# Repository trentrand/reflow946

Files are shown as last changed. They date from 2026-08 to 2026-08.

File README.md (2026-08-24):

# Reflow946

> **Fork notice** — This is a modified version of [Reflow946](https://github.com/DurandA/reflow946)
> by Arnaud Durand, licensed under the [Creative Commons Attribution 4.0 International
> license](LICENSE) (CC BY 4.0). See *Modifications* below for what changed.

The Reflow946 is a Bluetooth LE temperature controller for the 946C electronic hot plate. Using this controller, a reflow profile can be programmed from your web browser using the [Web Bluetooth](https://webbluetoothcg.github.io/web-bluetooth/) API. You can use preset profiles (e.g. for lead-free or leaded soldering) or create a custom profile for a perfect cheese fondue. 🫕

UYUE-946C

The controller board is intended to replace the original controller board. It is **only compatible with the 3 buttons variant** pictured above (see this [teardown](https://youtu.be/Gv2sRJ9y_Ok)). Please send a PR if you adapted the design to a new variant.

## Hardware

The controller is based on a ESP32 module with an IPEX antenna. Since the metal case acts as a Faraday cage, the BLE signal can be improved by taping an antenna outside of the case.

### Front

PCB front

### Back

PCB back

## Status

- [x] Temperature control
  - [x] Temperature control using the front panel
  - [x] [BLE GATT service](https://github.com/DurandA/reflow946-firmware/wiki/GATT-Services) for temperature control
- [x] Reflow profile programming
  - [x] [BLE GATT service](https://github.com/DurandA/reflow946-firmware/wiki/GATT-Services) for reflow profiles
  - [x] [Web Bluetooth application](https://duranda.github.io/reflow946/)

## Modifications

Changes by Trent Rand (Randware), relative to upstream rev 1.2:

- Pathfinder revision (rev 2): 3-digit 7-segment display (`DS1`) replaced by a
  1.47" IPS TFT (ST7789V3, 172x320) with two parallel interfaces:
  `J6` FH12-8S-0.5SH FPC connector (v2 mounting path) and `J9` 2.54mm breakout
  header (bench bring-up). Signals ride the former segment-drive GPIOs:
  BL=dp(IO5) CS=f(IO23) DC=d(IO16) RES=g(IO13) SDA=c(IO19) SCL=d2(IO18).
  One display may be attached at a time (shared bus).
- Second MAX31855KASA (`U6`) with screw terminal `J8` (`EXT_TC`) for top-of-PCB
  thermocouple profiling; shares CLK/MISO with the primary sensor, CS on IO4.
- Breakout `J7` (CLK / MISO / CS_EXT / TC_ADC / 3V3 / GND): digital probe amps
  on the shared SPI bus, or analog amplifiers (AD8495) on TC_ADC = SENSOR_VP.
- IO17/IO22 left as spare GPIOs (I2C-capable; add pull-ups with the device).

Upstream hardware errata and revision notes are preserved in [`hardware/README.md`](hardware/README.md).

## Credits

* Arnaud Durand - Original design ([CC BY 4.0](https://creativecommons.org/licenses/by/4.0/))
* Elías Rodríguez Martín - Revision 1.1, conversion to KiCad
* Trent Rand (Randware) - OLED display interface, external probe interface

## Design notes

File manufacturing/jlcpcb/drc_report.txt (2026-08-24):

** Drc report for reflow946.kicad_pcb **
** Created on 2026-08-24T14:50:08 **
** Report includes: Errors, Warnings, Exclusions **

** Found 258 DRC violations **
[starved_thermal]: Thermal relief connection to zone incomplete (layer F.Cu; zone min spoke count 2; actual 1)
    Local override; error
    @(168.5000 mm, 98.0000 mm): Zone [GND] on F.Cu, priority 0
    @(122.5000 mm, 111.5000 mm): PTH pad 2 [GND] of SW3
[track_dangling]: Track has unconnected end
    Local override; warning
    @(165.5400 mm, 82.3300 mm): Track [+3.3V] on B.Cu, length 4.5800 mm
[via_dangling]: Via is not connected or connected on only one layer
    Local override; warning
    @(154.0500 mm, 96.3000 mm): Via [/dp] on F.Cu - B.Cu
[track_dangling]: Track has unconnected end
    Local override; warning
    @(150.2600 mm, 86.9800 mm): Track [/d2] on F.Cu, length 0.0283 mm
[silk_edge_clearance]: Silkscreen clipped by board edge
    Rule: board setup constraints silk; warning
    @(174.5007 mm, 101.0007 mm): Segment on Edge.Cuts
    @(172.6600 mm, 120.3100 mm): Segment of U1 on F.Silkscreen
[silk_edge_clearance]: Silkscreen clipped by board edge
    Rule: board setup constraints silk; warning
    @(174.5007 mm, 101.0007 mm): Segment on Edge.Cuts
    @(174.9100 mm, 112.5700 mm): Arc of U1 on F.Silkscreen
[silk_edge_clearance]: Silkscreen clipped by board edge
    Rule: board setup constraints silk; warning
    @(103.7000 mm, 126.4000 mm): NPTH pad of REF**
    @(106.6300 mm, 127.6800 mm): Reference field of J7
[lib_footprint_mismatch]: Footprint 'PinHeader_2x03_P2.54mm_Vertical' does not match copy in library 'Connector_PinHeader_2.54mm'
    Local override; warning
    @(108.6750 mm, 74.0750 mm): Footprint J5
[lib_footprint_mismatch]: Footprint 'ESP32-WROOM-32U' does not match copy in library 'RF_Module'
    Local override; warning
    @(116.0000 mm, 99.8000 mm): Footprint U2
[lib_footprint_mismatch]: Footprint 'R_0603_1608Metric_Pad0.98x0.95mm_HandSolder' does not match copy in library 'Resistor_SMD'
    Local override; warning
    @(143.9000 mm, 92.2000 mm): Footprint R12
[lib_footprint_mismatch]: Footprint 'C_0805_2012Metric_Pad1.18x1.45mm_HandSolder' does not match copy in library 'Capacitor_SMD'
    Local override; warning
    @(112.9000 mm, 111.7000 mm): Footprint C6
[lib_footprint_mismatch]: Footprint 'C_0805_2012Metric_Pad1.18x1.45mm_HandSolder' does not match copy in library 'Capacitor_SMD'
    Local override; warning
    @(133.4000 mm, 72.9000 mm): Footprint C3
[lib_footprint_mismatch]: Footprint 'R_0603_1608Metric_Pad0.98x0.95mm_HandSolder' does not match copy in library 'Resistor_SMD'
    Local override; warning
    @(154.5000 mm, 120.0000 mm): Footprint R9
[lib_footprint_mismatch]: Footprint 'C_0805_2012Metric_Pad1.18x1.45mm_HandSolder' does not match copy in library 'Capacitor_SMD'
    Local override; warning
    @(107.7000 mm, 111.7000 mm): Footprint C5
[lib_footprint_mismatch]: Footprint 'R_0603_1608Metric_Pad0.98x0.95mm_HandSolder' does not match copy in library 'Resistor_SMD'
    Local override; warning
    @(108.0770 mm, 116.2000 mm): Footprint FB1
[lib_footprint_mismatch]: Footprint 'R_0603_1608Metric_Pad0.98x0.95mm_HandSolder' does not match copy in library 'Resistor_SMD'
    Local override; warning
    @(108.0770 mm, 118.6000 mm): Footprint FB2
[lib_footprint_mismatch]: Footprint 'R_0603_1608Metric_Pad0.98x0.95mm_HandSolder' does not match copy in library 'Resistor_SMD'
    Local override; warning
    @(117.7000 mm, 111.9000 mm): Footprint R1
[lib_footprint_mismatch]: Footprint 'R_0603_1608Metric_Pad0.98x0.95mm_HandSolder' does not match copy in library 'Resistor_SMD'
    Local override; warning
    @(146.4000 mm, 72.9000 mm): Footprint R17
[lib_footprint_mismatch]: Footprint 'R_0603_1608Metric_Pad0.98x0.95mm_HandSolder' does not match copy in library 'Resistor_SMD'
    Local override; warning
    @(143.9000 mm, 72.9000 mm): Footprint R16
[lib_footprint_mismatch]: Footprint 'CP_Radial_D10.0mm_P5.00mm' does not match copy in library 'Capacitor_THT'
    Local override; warning
    @(122.0000 mm, 78.2677 mm): Footprint C1
[lib_footprint_mismatch]: Footprint 'R_0603_1608Metric_Pad0.98x0.95mm_HandSolder' does not match copy in library 'Resistor_SMD'
    Local override; warning
    @(141.4000 mm, 92.2000 mm): Footprint R13
[lib_footprint_mismatch]: Footprint 'JST_VH_B2P3-VH_1x02_P7.92mm_Vertical' does not match copy in library 'Connector_JST'
    Local override; warning
    @(199.9000 mm, 94.6500 mm): Footprint J2
[lib_footprint_mismatch]: Footprint 'SOT-223-3_TabPin2' does not match copy in library 'Package_TO_SOT_SMD'
    Local override; warning
    @(131.2000 mm, 79.3000 mm): Footprint U4
[lib_footprint_mismatch]: Footprint 'JST_VH_B2P3-VH_1x02_P7.92mm_Vertical' does not match copy in library 'Connector_JST'
    Local override; warning
    @(199.9000 mm, 81.6500 mm): Footprint J3
[lib_footprint_mismatch]: Footprint 'R_Axial_DIN0414_L11.9mm_D4.5mm_P15.24mm_Horizontal' does not match copy in library 'Resistor_THT'
    Local override; warning
    @(190.9062 mm, 118.4605 mm): Footprint R5
[lib_footprint_mismatch]: Footprint 'C_0805_2012Metric_Pad1.18x1.45mm_HandSolder' does not match copy in library 'Capacitor_SMD'
    Local override; warning
    @(129.1000 mm, 72.9000 mm): Footprint C2
[lib_footprint_mismatch]: Footprint 'C_0805_2012Metric_Pad1.18x1.45mm_HandSolder' does not match copy in library 'Capacitor_SMD'
    Local override; warning
    @(110.8710 mm, 117.4000 mm): Footprint C4
[lib_footprint_mismatch]: Footprint 'SOT-23' does not match copy in library 'Package_TO_SOT_SMD'
    Local override; warning
    @(143.2000 mm, 80.9683 mm): Footprint Q3
[lib_footprint_mismatch]: Footprint 'R_0603_1608Metric_Pad0.98x0.95mm_HandSolder' does not match copy in library 'Resistor_SMD'
    Local override; warning
    @(148.2000 mm, 85.6839 mm): Footprint R18
[lib_footprint_mismatch]: Footprint 'DIP-6_W7.62mm_LongPads' does not match copy in library 'Package_DIP'
    Local override; warning
    @(171.1000 mm, 113.9000 mm): Footprint U1
[lib_footprint_mismatch]: Footprint 'R_Axial_DIN0309_L9.0mm_D3.2mm_P12.70mm_Horizontal' does not match copy in library 'Resistor_THT'
    Local override; warning
    @(178.1500 mm, 99.7000 mm): Footprint R4
[lib_footprint_mismatch]: Footprint 'R_0603_1608Metric_Pad0.98x0.95mm_HandSolder' does not match copy in library 'Resistor_SMD'
    Local override; warning
    @(143.2000 mm, 85.6839 mm): Footprint R19
[lib_footprint_mismatch]: Footprint 'R_0603_1608Metric_Pad0.98x0.95mm_HandSolder' does not match copy in library 'Resistor_SMD'
    Local override; warning
    @(138.9000 mm, 72.9000 mm): Footprint R15
[lib_footprint_mismatch]: Footprint 'SOT-23' does not match copy in library 'Package_TO_SOT_SMD'
    Local override; warning
    @(138.1000 mm, 80.9683 mm): Footprint Q4
[lib_footprint_mismatch]: Footprint 'R_0603_1608Metric_Pad0.98x0.95mm_HandSolder' does not match copy in library 'Resistor_SMD'
    Local override; warning
    @(138.8000 mm, 92.2000 mm): Footprint R14
[lib_footprint_mismatch]: Footprint 'JST_VH_B2P-VH_1x02_P3.96mm_Vertical' does not match copy in library 'Connector_JST'
    Local override; warning
    @(104.1000 mm, 84.0000 mm): Footprint J1
[lib_footprint_mismatch]: Footprint 'R_Axial_DIN0309_L9.0mm_D3.2mm_P12.70mm_Horizontal' does not match copy in library 'Resistor_THT'
    Local override; warning
    @(183.5000 mm, 118.9000 mm): Footprint R3
[lib_footprint_mismatch]: Footprint 'SOT-23' does not match copy in library 'Package_TO_SOT_SMD'
    Local override; warning
    @(148.0000 mm, 80.9683 mm): Footprint Q2
[lib_footprint_mismatch]: Footprint 'Fuse_0805_2012Metric_Pad1.15x1.40mm_HandSolder' does not match copy in library 'Fuse'
    Local override; warning
    @(111.7000 mm, 80.0000 mm): Footprint F1
[lib_footprint_mismatch]: Footprint 'R_0603_1608Metric_Pad0.98x0.95mm_HandSolder' does not match copy in library 'Resistor_SMD'
    Local override; warning
    @(127.5000 mm, 120.0000 mm): Footprint R7
[lib_footprint_mismatch]: Footprint 'R_0603_1608Metric_Pad0.98x0.95mm_HandSolder' does not match copy in library 'Resistor_SMD'
    Local override; warning
    @(138.2000 mm, 85.6839 mm): Footprint R20
[lib_footprint_mismatch]: Footprint 'TO-220-3_Horizontal_TabUp' does not match copy in library 'Package_TO_SOT_THT'
    Local override; warning
    @(183.2000 mm, 94.0550 mm): Footprint Q1
[lib_footprint_mismatch]: Footprint 'SOIC-8_3.9x4.9mm_P1.27mm' does not match copy in library 'Package_SO'
    Local override; warning
    @(114.9000 mm, 117.6000 mm): Footprint U3
[lib_footprint_mismatch]: Footprint 'R_0603_1608Metric_Pad0.98x0.95mm_HandSolder' does not match copy in library 'Resistor_SMD'
    Local override; warning
    @(146.5000 mm, 92.2000 mm): Footprint R11
[lib_footprint_mismatch]: Footprint 'R_0603_1608Metric_Pad0.98x0.95mm_HandSolder' does not match copy in library 'Resistor_SMD'
    Local override; warning
    @(138.5000 mm, 120.0000 mm): Footprint R8
[lib_footprint_mismatch]: Footprint 'R_0603_1608Metric_Pad0.98x0.95mm_HandSolder' does not match copy in library 'Resistor_SMD'
    Local override; warning
    @(149.0000 mm, 92.2000 mm): Footprint R10
[lib_footprint_mismatch]: Footprint 'R_0603_1608Metric_Pad0.98x0.95mm_HandSolder' does not match copy in library 'Resistor_SMD'
    Local override; warning
    @(110.3000 mm, 111.9000 mm): Footprint R6
[lib_footprint_mismatch]: Footprint 'C_Rect_L13.0mm_W6.0mm_P10.00mm_FKS3_FKP3_MKS4' does not match copy in library 'Capacitor_THT'
    Local override; warning
    @(197.8000 mm, 118.5000 mm): Footprint CCBB1
[text_height]: Text height out of range (board setup constraints silk text height min height 0.8000 mm; actual 0.7000 mm)
    Rule: board setup constraints silk text height; warning
    @(142.6200 mm, 128.9000 mm): PCB text 'Based on Reflow946 by A. Durand | CC BY 4.0' on F.Silkscreen
[silk_overlap]: Silkscreen clearance
    Rule: board setup constraints silk; warning
    @(145.1113 mm, 103.2000 mm): Reference field of J8
    @(143.7912 mm, 103.0300 mm): Reference field of FB3
[silk_overlap]: Silkscreen clearance
    Rule: board setup constraints silk; warning
    @(143.3775 mm, 92.4547 mm): Segment of R12 on F.Silkscreen
    @(124.6250 mm, 72.7250 mm): Rectangle on F.Silkscreen
[silk_overlap]: Silkscreen clearance
    Rule: board setup constraints silk; warning
    @(140.8775 mm, 92.4547 mm): Segment of R13 on F.Silkscreen
    @(124.6250 mm, 72.7250 mm): Rectangle on F.Silkscreen
[silk_overlap]: Silkscreen clearance
    Rule: board setup constraints silk; warning
    @(143.5365 mm, 102.5825 mm): Segment of FB4 on F.Silkscreen
    @(143.7912 mm, 103.0300 mm): Reference field of FB3
[silk_overlap]: Silkscreen clearance
    Rule: board setup constraints silk; warning
    @(138.2775 mm, 92.4547 mm): Segment of R14 on F.Silkscreen
    @(124.6250 mm, 72.7250 mm): Rectangle on F.Silkscreen
[silk_overlap]: Silkscreen clearance
    Rule: board setup constraints silk; warning
    @(124.6250 mm, 72.7250 mm): Rectangle on F.Silkscreen
    @(139.3225 mm, 92.4547 mm): Segment of R14 on F.Silkscreen
[silk_overlap]: Silkscreen clearance
    Rule: board setup constraints silk; warning
    @(144.4225 mm, 92.4547 mm): Segment of R12 on F.Silkscreen
    @(124.6250 mm, 72.7250 mm): Rectangle on F.Silkscreen
[silk_overlap]: Silkscreen clearance
    Rule: board setup constraints silk; warning
    @(124.6250 mm, 72.7250 mm): Rectangle on F.Silkscreen
    @(141.9225 mm, 92.4547 mm): Segment of R13 on F.Silkscreen
[silk_overlap]: Silkscreen clearance
    Rule: board setup constraints silk; warning
    @(124.6250 mm, 72.7250 mm): Rectangle on F.Silkscreen
    @(145.9775 mm, 92.4547 mm): Segment of R11 on F.Silkscreen
[silk_overlap]: Silkscreen clearance
    Rule: board setup constraints silk; warning
    @(147.0225 mm, 92.4547 mm): Segment of R11 on F.Silkscreen
    @(124.6250 mm, 72.7250 mm): Rectangle on F.Silkscreen
[silk_overlap]: Silkscreen clearance
    Rule: board setup constraints silk; warning
    @(148.4775 mm, 92.4547 mm): Segment of R10 on F.Silkscreen
    @(124.6250 mm, 72.7250 mm): Rectangle on F.Silkscreen
[silk_overlap]: Silkscreen clearance
    Rule: board setup constraints silk; warning
    @(124.6250 mm, 72.7250 mm): Rectangle on F.Silkscreen
    @(149.5225 mm, 92.4547 mm): Segment of R10 on F.Silkscreen
[silk_overlap]: Silkscreen clearance
    Rule: board setup constraints silk; warning
    @(126.4250 mm, 73.7250 mm): Rectangle on F.Silkscreen
    @(154.2900 mm, 91.0400 mm): Segment of J9 on F.Silkscreen
[silk_overlap]: Silkscreen clearance
    Rule: board setup constraints silk; warning
    @(126.4250 mm, 73.7250 mm): Rectangle on F.Silkscreen
    @(155.6700 mm, 91.0400 mm): Segment of J9 on F.Silkscreen
[silk_overlap]: Silkscreen clearance
    Rule: board setup constraints silk; warning
    @(126.4250 mm, 73.7250 mm): Rectangle on F.Silkscreen
    @(147.9000 mm, 72.9000 mm): Reference field of R17
[silk_overlap]: Silkscreen clearance
    Rule: board setup constraints silk; warning
    @(124.6250 mm, 72.7250 mm): Rectangle on F.Silkscreen
    @(147.9000 mm, 72.9000 mm): Reference field of R17
[silk_overlap]: Silkscreen clearance
    Rule: board setup constraints silk; warning
    @(145.8775 mm, 72.6453 mm): Segment of R17 on F.Silkscreen
    @(124.6250 mm, 72.7250 mm): Rectangle on F.Silkscreen
[silk_overlap]: Silkscreen clearance
    Rule: board setup constraints silk; warning
    @(124.6250 mm, 72.7250 mm): Rectangle on F.Silkscreen
    @(146.9225 mm, 72.6453 mm): Segment of R17 on F.Silkscreen
[silk_overlap]: Silkscreen clearance
    Rule: board setup constraints silk; warning
    @(126.4250 mm, 73.7250 mm): Rectangle on F.Silkscreen
    @(142.5000 mm, 72.9000 mm): Reference field of R16
[silk_overlap]: Silkscreen clearance
    Rule: board setup constraints silk; warning
    @(124.6250 mm, 72.7250 mm): Rectangle on F.Silkscreen
    @(142.5000 mm, 72.9000 mm): Reference field of R16
[silk_overlap]: Silkscreen clearance
    Rule: board setup constraints silk; warning
    @(124.6250 mm, 72.7250 mm): Rectangle on F.Silkscreen
    @(143.3775 mm, 72.6453 mm): Segment of R16 on F.Silkscreen
[silk_overlap]: Silkscreen clearance
    Rule: board setup constraints silk; warning
    @(124.6250 mm, 72.7250 mm): Rectangle on F.Silkscreen
    @(144.4225 mm, 72.6453 mm): Segment of R16 on F.Silkscreen
[silk_overlap]: Silkscreen clearance
    Rule: board setup constraints silk; warning
    @(142.6250 mm, 71.1750 mm): PCB text 'ST7789V3 ALIGN 32.4x17.3' on F.Silkscreen
    @(133.4000 mm, 71.3000 mm): Reference field of C3
[silk_overlap]: Silkscreen clearance
    Rule: board setup constraints silk; warning
    @(126.4250 mm, 73.7250 mm): Rectangle on F.Silkscreen
    @(140.3300 mm, 72.9000 mm): Reference field of R15
[silk_overlap]: Silkscreen clearance
    Rule: board setup constraints silk; warning
    @(140.3300 mm, 72.9000 mm): Reference field of R15
    @(124.6250 mm, 72.7250 mm): Rectangle on F.Silkscreen
[silk_overlap]: Silkscreen clearance
    Rule: board setup constraints silk; warning
    @(124.6250 mm, 72.7250 mm): Rectangle on F.Silkscreen
    @(138.3775 mm, 72.6453 mm): Segment of R15 on F.Silkscreen
[silk_overlap]: Silkscreen clearance
    Rule: board setup constraints silk; warning
    @(139.4225 mm, 72.6453 mm): Segment of R15 on F.Silkscreen
    @(124.6250 mm, 72.7250 mm): Rectangle on F.Silkscreen
[silk_overlap]: Silkscreen clearance
    Rule: board setup constraints silk; warning
    @(126.4250 mm, 73.7250 mm): Rectangle on F.Silkscreen
    @(133.1387 mm, 73.6350 mm): Segment of C3 on F.Silkscreen
[silk_overlap]: Silkscreen clearance
    Rule: board setup constraints silk; warning
    @(129.3613 mm, 73.6350 mm): Segment of C2 on F.Silkscreen
    @(126.4250 mm, 73.7250 mm): Rectangle on F.Silkscreen
[silk_overlap]: Silkscreen clearance
    Rule: board setup constraints silk; warning
    @(116.9300 mm, 75.4477 mm): Segment of C1 on F.Silkscreen
    @(124.6250 mm, 72.7250 mm): Rectangle on F.Silkscreen
[silk_overlap]: Silkscreen clearance
    Rule: board setup constraints silk; warning
    @(126.4250 mm, 73.7250 mm): Rectangle on F.Silkscreen
    @(116.9300 mm, 75.4477 mm): Segment of C1 on F.Silkscreen
[silk_overlap]: Silkscreen clearance
    Rule: board setup constraints silk; warning
    @(124.6250 mm, 72.7250 mm): Rectangle on F.Silkscreen
    @(116.9320 mm, 75.4077 mm): Segment of C1 on F.Silkscreen
[silk_overlap]: Silkscreen clearance
    Rule: board setup constraints silk; warning
    @(126.4250 mm, 73.7250 mm): Rectangle on F.Silkscreen
    @(116.9320 mm, 75.4077 mm): Segment of C1 on F.Silkscreen
[silk_overlap]: Silkscreen clearance
    Rule: board setup constraints silk; warning
    @(116.9350 mm, 75.3677 mm): Segment of C1 on F.Silkscreen
    @(124.6250 mm, 72.7250 mm): Rectangle on F.Silkscreen
[silk_overlap]: Silkscreen clearance
    Rule: board setup constraints silk; warning
    @(126.4250 mm, 73.7250 mm): Rectangle on F.Silkscreen
    @(116.9350 mm, 75.3677 mm): Segment of C1 on F.Silkscreen
[silk_overlap]: Silkscreen clearance
    Rule: board setup constraints silk; warning
    @(124.6250 mm, 72.7250 mm): Rectangle on F.Silkscreen
    @(116.9380 mm, 75.3277 mm): Segment of C1 on F.Silkscreen
[silk_overlap]: Silkscreen clearance
    Rule: board setup constraints silk; warning
    @(126.4250 mm, 73.7250 mm): Rectangle on F.Silkscreen
    @(116.9380 mm, 75.3277 mm): Segment of C1 on F.Silkscreen
[silk_overlap]: Silkscreen clearance
    Rule: board setup constraints silk; warning
    @(124.6250 mm, 72.7250 mm): Rectangle on F.Silkscreen
    @(116.9420 mm, 75.2877 mm): Segment of C1 on F.Silkscreen
[silk_overlap]: Silkscreen clearance
    Rule: board setup constraints silk; warning
    @(126.4250 mm, 73.7250 mm): Rectangle on F.Silkscreen
    @(116.9420 mm, 75.2877 mm): Segment of C1 on F.Silkscreen
[silk_overlap]: Silkscreen clearance
    Rule: board setup constraints silk; warning
    @(124.6250 mm, 72.7250 mm): Rectangle on F.Silkscreen
    @(116.9460 mm, 75.2477 mm): Segment of C1 on F.Silkscreen
[silk_overlap]: Silkscreen clearance
    Rule: board setup constraints silk; warning
    @(126.4250 mm, 73.7250 mm): Rectangle on F.Silkscreen
    @(116.9460 mm, 75.2477 mm): Segment of C1 on F.Silkscreen
[silk_overlap]: Silkscreen clearance
    Rule: board setup constraints silk; warning
    @(124.6250 mm, 72.7250 mm): Rectangle on F.Silkscreen
    @(116.9500 mm, 75.2077 mm): Segment of C1 on F.Silkscreen
[silk_overlap]: Silkscreen clearance
    Rule: board setup constraints silk; warning
    @(126.4250 mm, 73.7250 mm): Rectangle on F.Silkscreen
    @(116.9500 mm, 75.2077 mm): Segment of C1 on F.Silkscreen
[silk_overlap]: Silkscreen clearance
    Rule: board setup constraints silk; warning
    @(124.6250 mm, 72.7250 mm): Rectangle on F.Silkscreen
    @(116.9550 mm, 75.1677 mm): Segment of C1 on F.Silkscreen
[silk_overlap]: Silkscreen clearance
    Rule: board setup constraints silk; warning
    @(126.4250 mm, 73.7250 mm): Rectangle on F.Silkscreen
    @(116.9550 mm, 75.1677 mm): Segment of C1 on F.Silkscreen
[silk_overlap]: Silkscreen clearance
    Rule: board setup constraints silk; warning
    @(124.6250 mm, 72.7250 mm): Rectangle on F.Silkscreen
    @(116.9600 mm, 75.1277 mm): Segment of C1 on F.Silkscreen
[silk_overlap]: Silkscreen clearance
    Rule: board setup constraints silk; warning
    @(126.4250 mm, 73.7250 mm): Rectangle on F.Silkscreen
    @(116.9600 mm, 75.1277 mm): Segment of C1 on F.Silkscreen
[silk_overlap]: Silkscreen clearance
    Rule: board setup constraints silk; warning
    @(124.6250 mm, 72.7250 mm): Rectangle on F.Silkscreen
    @(116.9650 mm, 75.0877 mm): Segment of C1 on F.Silkscreen
[silk_overlap]: Silkscreen clearance
    Rule: board setup constraints silk; warning
    @(126.4250 mm, 73.7250 mm): Rectangle on F.Silkscreen
    @(116.9650 mm, 75.0877 mm): Segment of C1 on F.Silkscreen
[silk_overlap]: Silkscreen clearance
    Rule: board setup constraints silk; warning
    @(124.6250 mm, 72.7250 mm): Rectangle on F.Silkscreen
    @(116.9700 mm, 75.0467 mm): Segment of C1 on F.Silkscreen
[silk_overlap]: Silkscreen clearance
    Rule: board setup constraints silk; warning
    @(126.4250 mm, 73.7250 mm): Rectangle on F.Silkscreen
    @(116.9700 mm, 75.0467 mm): Segment of C1 on F.Silkscreen
[silk_overlap]: Silkscreen clearance
    Rule: board setup constraints silk; warning
    @(124.6250 mm, 72.7250 mm): Rectangle on F.Silkscreen
    @(116.9760 mm, 75.0067 mm): Segment of C1 on F.Silkscreen
[silk_overlap]: Silkscreen clearance
    Rule: board setup constraints silk; warning
    @(126.4250 mm, 73.7250 mm): Rectangle on F.Silkscreen
    @(116.9760 mm, 75.0067 mm): Segment of C1 on F.Silkscreen
[silk_overlap]: Silkscreen clearance
    Rule: board setup constraints silk; warning
    @(124.6250 mm, 72.7250 mm): Rectangle on F.Silkscreen
    @(116.9820 mm, 74.9667 mm): Segment of C1 on F.Silkscreen
[silk_overlap]: Silkscreen clearance
    Rule: board setup constraints silk; warning
    @(126.4250 mm, 73.7250 mm): Rectangle on F.Silkscreen
    @(116.9820 mm, 74.9667 mm): Segment of C1 on F.Silkscreen
[silk_overlap]: Silkscreen clearance
    Rule: board setup constraints silk; warning
    @(116.9890 mm, 74.9267 mm): Segment of C1 on F.Silkscreen
    @(124.6250 mm, 72.7250 mm): Rectangle on F.Silkscreen
[silk_overlap]: Silkscreen clearance
    Rule: board setup constraints silk; warning
    @(126.4250 mm, 73.7250 mm): Rectangle on F.Silkscreen
    @(116.9890 mm, 74.9267 mm): Segment of C1 on F.Silkscreen
[silk_overlap]: Silkscreen clearance
    Rule: board setup constraints silk; warning
    @(116.9960 mm, 74.8867 mm): Segment of C1 on F.Silkscreen
    @(124.6250 mm, 72.7250 mm): Rectangle on F.Silkscreen
[silk_overlap]: Silkscreen clearance
    Rule: board setup constraints silk; warning
    @(126.4250 mm, 73.7250 mm): Rectangle on F.Silkscreen
    @(116.9960 mm, 74.8867 mm): Segment of C1 on F.Silkscreen
[silk_overlap]: Silkscreen clearance
    Rule: board setup constraints silk; warning
    @(124.6250 mm, 72.7250 mm): Rectangle on F.Silkscreen
    @(117.0030 mm, 74.8467 mm): Segment of C1 on F.Silkscreen
[silk_overlap]: Silkscreen clearance
    Rule: board setup constraints silk; warning
    @(126.4250 mm, 73.7250 mm): Rectangle on F.Silkscreen
    @(117.0030 mm, 74.8467 mm): Segment of C1 on F.Silkscreen
[silk_overlap]: Silkscreen clearance
    Rule: board setup constraints silk; warning
    @(124.6250 mm, 72.7250 mm): Rectangle on F.Silkscreen
    @(117.0100 mm, 74.8067 mm): Segment of C1 on F.Silkscreen
[silk_overlap]: Silkscreen clearance
    Rule: board setup constraints silk; warning
    @(126.4250 mm, 73.7250 mm): Rectangle on F.Silkscreen
    @(117.0100 mm, 74.8067 mm): Segment of C1 on F.Silkscreen
[silk_overlap]: Silkscreen clearance
    Rule: board setup constraints silk; warning
    @(117.0180 mm, 74.7667 mm): Segment of C1 on F.Silkscreen
    @(124.6250 mm, 72.7250 mm): Rectangle on F.Silkscreen
[silk_overlap]: Silkscreen clearance
    Rule: board setup constraints silk; warning
    @(126.4250 mm, 73.7250 mm): Rectangle on F.Silkscreen
    @(117.0180 mm, 74.7667 mm): Segment of C1 on F.Silkscreen
[silk_overlap]: Silkscreen clearance
    Rule: board setup constraints silk; warning
    @(124.6250 mm, 72.7250 mm): Rectangle on F.Silkscreen
    @(117.0260 mm, 74.7267 mm): Segment of C1 on F.Silkscreen
[silk_overlap]: Silkscreen clearance
    Rule: board setup constraints silk; warning
    @(126.4250 mm, 73.7250 mm): Rectangle on F.Silkscreen
    @(117.0260 mm, 74.7267 mm): Segment of C1 on F.Silkscreen
[silk_overlap]: Silkscreen clearance
    Rule: board setup constraints silk; warning
    @(124.6250 mm, 72.7250 mm): Rectangle on F.Silkscreen
    @(117.0350 mm, 74.6867 mm): Segment of C1 on F.Silkscreen
[silk_overlap]: Silkscreen clearance
    Rule: board setup constraints silk; warning
    @(126.4250 mm, 73.7250 mm): Rectangle on F.Silkscreen
    @(117.0350 mm, 74.6867 mm): Segment of C1 on F.Silkscreen
[silk_overlap]: Silkscreen clearance
    Rule: board setup constraints silk; warning
    @(124.6250 mm, 72.7250 mm): Rectangle on F.Silkscreen
    @(117.0440 mm, 74.6467 mm): Segment of C1 on F.Silkscreen
[silk_overlap]: Silkscreen clearance
    Rule: board setup constraints silk; warning
    @(126.4250 mm, 73.7250 mm): Rectangle on F.Silkscreen
    @(117.0440 mm, 74.6467 mm): Segment of C1 on F.Silkscreen
[silk_overlap]: Silkscreen clearance
    Rule: board setup constraints silk; warning
    @(117.0530 mm, 74.6067 mm): Segment of C1 on F.Silkscreen
    @(124.6250 mm, 72.7250 mm): Rectangle on F.Silkscreen
[silk_overlap]: Silkscreen clearance
    Rule: board setup constraints silk; warning
    @(126.4250 mm, 73.7250 mm): Rectangle on F.Silkscreen
    @(117.0530 mm, 74.6067 mm): Segment of C1 on F.Silkscreen
[silk_overlap]: Silkscreen clearance
    Rule: board setup constraints silk; warning
    @(117.0620 mm, 74.5667 mm): Segment of C1 on F.Silkscreen
    @(124.6250 mm, 72.7250 mm): Rectangle on F.Silkscreen
[silk_overlap]: Silkscreen clearance
    Rule: board setup constraints silk; warning
    @(126.4250 mm, 73.7250 mm): Rectangle on F.Silkscreen
    @(117.0620 mm, 74.5667 mm): Segment of C1 on F.Silkscreen
[silk_overlap]: Silkscreen clearance
    Rule: board setup constraints silk; warning
    @(123.2410 mm, 72.6067 mm): Segment of C1 on F.Silkscreen
    @(124.6250 mm, 72.7250 mm): Rectangle on F.Silkscreen
[silk_overlap]: Silkscreen clearance
    Rule: board setup constraints silk; warning
    @(123.2410 mm, 72.6467 mm): Segment of C1 on F.Silkscreen
    @(124.6250 mm, 72.7250 mm): Rectangle on F.Silkscreen
[silk_overlap]: Silkscreen clearance
    Rule: board setup constraints silk; warning
    @(124.6250 mm, 72.7250 mm): Rectangle on F.Silkscreen
    @(123.2410 mm, 72.6867 mm): Segment of C1 on F.Silkscreen
[silk_overlap]: Silkscreen clearance
    Rule: board setup constraints silk; warning
    @(124.6250 mm, 72.7250 mm): Rectangle on F.Silkscreen
    @(123.2410 mm, 72.7267 mm): Segment of C1 on F.Silkscreen
[silk_overlap]: Silkscreen clearance
    Rule: board setup constraints silk; warning
    @(123.2410 mm, 72.7667 mm): Segment of C1 on F.Silkscreen
    @(124.6250 mm, 72.7250 mm): Rectangle on F.Silkscreen
[silk_overlap]: Silkscreen clearance
    Rule: board setup constraints silk; warning
    @(124.6250 mm, 72.7250 mm): Rectangle on F.Silkscreen
    @(123.2410 mm, 72.8067 mm): Segment of C1 on F.Silkscreen
[silk_overlap]: Silkscreen clearance
    Rule: board setup constraints silk; warning
    @(123.2410 mm, 72.8467 mm): Segment of C1 on F.Silkscreen
    @(124.6250 mm, 72.7250 mm): Rectangle on F.Silkscreen
[silk_overlap]: Silkscreen clearance
    Rule: board setup constraints silk; warning
    @(123.2410 mm, 72.8867 mm): Segment of C1 on F.Silkscreen
    @(124.6250 mm, 72.7250 mm): Rectangle on F.Silkscreen
[silk_overlap]: Silkscreen clearance
    Rule: board setup constraints silk; warning
    @(124.6250 mm, 72.7250 mm): Rectangle on F.Silkscreen
    @(123.2410 mm, 72.9267 mm): Segment of C1 on F.Silkscreen
[silk_overlap]: Silkscreen clearance
    Rule: board setup constraints silk; warning
    @(124.6250 mm, 72.7250 mm): Rectangle on F.Silkscreen
    @(123.2410 mm, 72.9667 mm): Segment of C1 on F.Silkscreen
[silk_overlap]: Silkscreen clearance
    Rule: board setup constraints silk; warning
    @(124.6250 mm, 72.7250 mm): Rectangle on F.Silkscreen
    @(123.2410 mm, 73.0067 mm): Segment of C1 on F.Silkscreen
[silk_overlap]: Silkscreen clearance
    Rule: board setup constraints silk; warning
    @(123.2410 mm, 73.0467 mm): Segment of C1 on F.Silkscreen
    @(124.6250 mm, 72.7250 mm): Rectangle on F.Silkscreen
[silk_overlap]: Silkscreen clearance
    Rule: board setup constraints silk; warning
    @(123.2410 mm, 73.0867 mm): Segment of C1 on F.Silkscreen
    @(124.6250 mm, 72.7250 mm): Rectangle on F.Silkscreen
[silk_overlap]: Silkscreen clearance
    Rule: board setup constraints silk; warning
    @(123.2410 mm, 73.1267 mm): Segment of C1 on F.Silkscreen
    @(124.6250 mm, 72.7250 mm): Rectangle on F.Silkscreen
[silk_overlap]: Silkscreen clearance
    Rule: board setup constraints silk; warning
    @(123.2410 mm, 73.1667 mm): Segment of C1 on F.Silkscreen
    @(124.6250 mm, 72.7250 mm): Rectangle on F.Silkscreen
[silk_overlap]: Silkscreen clearance
    Rule: board setup constraints silk; warning
    @(124.6250 mm, 72.7250 mm): Rectangle on F.Silkscreen
    @(123.2410 mm, 73.2067 mm): Segment of C1 on F.Silkscreen
[silk_overlap]: Silkscreen clearance
    Rule: board setup constraints silk; warning
    @(124.6250 mm, 72.7250 mm): Rectangle on F.Silkscreen
    @(123.2410 mm, 73.2467 mm): Segment of C1 on F.Silkscreen
[silk_overlap]: Silkscreen clearance
    Rule: board setup constraints silk; warning
    @(124.6250 mm, 72.7250 mm): Rectangle on F.Silkscreen
    @(123.2410 mm, 73.2867 mm): Segment of C1 on F.Silkscreen
[silk_overlap]: Silkscreen clearance
    Rule: board setup constraints silk; warning
    @(124.6250 mm, 72.7250 mm): Rectangle on F.Silkscreen
    @(123.2410 mm, 73.3267 mm): Segment of C1 on F.Silkscreen
[silk_overlap]: Silkscreen clearance
    Rule: board setup constraints silk; warning
    @(123.2410 mm, 73.3667 mm): Segment of C1 on F.Silkscreen
    @(124.6250 mm, 72.7250 mm): Rectangle on F.Silkscreen
[silk_overlap]: Silkscreen clearance
    Rule: board setup constraints silk; warning
    @(123.2410 mm, 73.4067 mm): Segment of C1 on F.Silkscreen
    @(124.6250 mm, 72.7250 mm): Rectangle on F.Silkscreen
[silk_overlap]: Silkscreen clearance
    Rule: board setup constraints silk; warning
    @(123.2410 mm, 73.4467 mm): Segment of C1 on F.Silkscreen
    @(124.6250 mm, 72.7250 mm): Rectangle on F.Silkscreen
[silk_overlap]: Silkscreen clearance
    Rule: board setup constraints silk; warning
    @(123.2410 mm, 73.4867 mm): Segment of C1 on F.Silkscreen
    @(124.6250 mm, 72.7250 mm): Rectangle on F.Silkscreen
[silk_overlap]: Silkscreen clearance
    Rule: board setup constraints silk; warning
    @(124.6250 mm, 72.7250 mm): Rectangle on F.Silkscreen
    @(123.2410 mm, 73.5267 mm): Segment of C1 on F.Silkscreen
[silk_overlap]: Silkscreen clearance
    Rule: board setup constraints silk; warning
    @(124.6250 mm, 72.7250 mm): Rectangle on F.Silkscreen
    @(123.2410 mm, 73.5667 mm): Segment of C1 on F.Silkscreen
[silk_overlap]: Silkscreen clearance
    Rule: board setup constraints silk; warning
    @(156.9400 mm, 88.2800 mm): Segment of J9 on F.Silkscreen
    @(124.6250 mm, 72.7250 mm): Rectangle on F.Silkscreen
[silk_overlap]: Silkscreen clearance
    Rule: board setup constraints silk; warning
    @(124.6250 mm, 72.7250 mm): Rectangle on F.Silkscreen
    @(156.9400 mm, 91.0400 mm): Segment of J9 on F.Silkscreen
[silk_overlap]: Silkscreen clearance
    Rule: board setup constraints silk; warning
    @(126.4250 mm, 73.7250 mm): Rectangle on F.Silkscreen
    @(156.9400 mm, 88.2800 mm): Segment of J9 on F.Silkscreen
[silk_overlap]: Silkscreen clearance
    Rule: board setup constraints silk; warning
    @(126.4250 mm, 73.7250 mm): Rectangle on F.Silkscreen
    @(156.9400 mm, 91.0400 mm): Segment of J9 on F.Silkscreen
[silk_overlap]: Silkscreen clearance
    Rule: board setup constraints silk; warning
    @(125.3250 mm, 89.2000 mm): Reference field of U2
    @(124.6250 mm, 72.7250 mm): Rectangle on F.Silkscreen
[silk_overlap]: Silkscreen clearance
    Rule: board setup constraints silk; warning
    @(126.4250 mm, 73.7250 mm): Rectangle on F.Silkscreen
    @(156.9400 mm, 91.0400 mm): Segment of J9 on F.Silkscreen
[silk_overlap]: Silkscreen clearance
    Rule: board setup constraints silk; warning
    @(116.9200 mm, 75.6877 mm): Segment of C1 on F.Silkscreen
    @(124.6250 mm, 72.7250 mm): Rectangle on F.Silkscreen
[silk_overlap]: Silkscreen clearance
    Rule: board setup constraints silk; warning
    @(124.6250 mm, 72.7250 mm): Rectangle on F.Silkscreen
    @(116.9200 mm, 75.7277 mm): Segment of C1 on F.Silkscreen
[silk_overlap]: Silkscreen clearance
    Rule: board setup constraints silk; warning
    @(124.6250 mm, 72.7250 mm): Rectangle on F.Silkscreen
    @(116.9200 mm, 75.7677 mm): Segment of C1 on F.Silkscreen
[silk_overlap]: Silkscreen clearance
    Rule: board setup constraints silk; warning
    @(124.6250 mm, 72.7250 mm): Rectangle on F.Silkscreen
    @(122.0000 mm, 75.7677 mm): Circle of C1 on F.Silkscreen
[silk_overlap]: Silkscreen clearance
    Rule: board setup constraints silk; warning
    @(116.9210 mm, 75.6477 mm): Segment of C1 on F.Silkscreen
    @(124.6250 mm, 72.7250 mm): Rectangle on F.Silkscreen
[silk_overlap]: Silkscreen clearance
    Rule: board setup constraints silk; warning
    @(116.9220 mm, 75.6077 mm): Segment of C1 on F.Silkscreen
    @(124.6250 mm, 72.7250 mm): Rectangle on F.Silkscreen
[silk_overlap]: Silkscreen clearance
    Rule: board setup constraints silk; warning
    @(116.9230 mm, 75.5677 mm): Segment of C1 on F.Silkscreen
    @(124.6250 mm, 72.7250 mm): Rectangle on F.Silkscreen
[silk_overlap]: Silkscreen clearance
    Rule: board setup constraints silk; warning
    @(116.9250 mm, 75.5277 mm): Segment of C1 on F.Silkscreen
    @(124.6250 mm, 72.7250 mm): Rectangle on F.Silkscreen
[silk_overlap]: Silkscreen clearance
    Rule: board setup constraints silk; warning
    @(116.9270 mm, 75.4877 mm): Segment of C1 on F.Silkscreen
    @(124.6250 mm, 72.7250 mm): Rectangle on F.Silkscreen
[silk_overlap]: Silkscreen clearance
    Rule: board setup constraints silk; warning
    @(124.6250 mm, 72.7250 mm): Rectangle on F.Silkscreen
    @(117.0720 mm, 74.5267 mm): Segment of C1 on F.Silkscreen
[silk_overlap]: Silkscreen clearance
    Rule: board setup constraints silk; warning
    @(124.6250 mm, 72.7250 mm): Rectangle on F.Silkscreen
    @(123.2410 mm, 74.2867 mm): Segment of C1 on F.Silkscreen
[silk_overlap]: Silkscreen clearance
    Rule: board setup constraints silk; warning
    @(124.6250 mm, 72.7250 mm): Rectangle on F.Silkscreen
    @(123.2410 mm, 74.3267 mm): Segment of C1 on F.Silkscreen
[silk_overlap]: Silkscreen clearance
    Rule: board setup constraints silk; warning
    @(124.6250 mm, 72.7250 mm): Rectangle on F.Silkscreen
    @(123.2410 mm, 74.3667 mm): Segment of C1 on F.Silkscreen
[silk_overlap]: Silkscreen clearance
    Rule: board setup constraints silk; warning
    @(123.2410 mm, 74.4067 mm): Segment of C1 on F.Silkscreen
    @(124.6250 mm, 72.7250 mm): Rectangle on F.Silkscreen
[silk_overlap]: Silkscreen clearance
    Rule: board setup constraints silk; warning
    @(123.2410 mm, 74.4467 mm): Segment of C1 on F.Silkscreen
    @(124.6250 mm, 72.7250 mm): Rectangle on F.Silkscreen
[silk_overlap]: Silkscreen clearance
    Rule: board setup constraints silk; warning
    @(123.2410 mm, 74.4867 mm): Segment of C1 on F.Silkscreen
    @(124.6250 mm, 72.7250 mm): Rectangle on F.Silkscreen
[silk_overlap]: Silkscreen clearance
    Rule: board setup constraints silk; warning
    @(123.2410 mm, 73.6067 mm): Segment of C1 on F.Silkscreen
    @(124.6250 mm, 72.7250 mm): Rectangle on F.Silkscreen
[silk_overlap]: Silkscreen clearance
    Rule: board setup constraints silk; warning
    @(123.2410 mm, 73.6467 mm): Segment of C1 on F.Silkscreen
    @(124.6250 mm, 72.7250 mm): Rectangle on F.Silkscreen
[silk_overlap]: Silkscreen clearance
    Rule: board setup constraints silk; warning
    @(124.6250 mm, 72.7250 mm): Rectangle on F.Silkscreen
    @(123.2410 mm, 73.6867 mm): Segment of C1 on F.Silkscreen
[silk_overlap]: Silkscreen clearance
    Rule: board setup constraints silk; warning
    @(123.2410 mm, 73.7267 mm): Segment of C1 on F.Silkscreen
    @(124.6250 mm, 72.7250 mm): Rectangle on F.Silkscreen
[silk_overlap]: Silkscreen clearance
    Rule: board setup constraints silk; warning
    @(124.6250 mm, 72.7250 mm): Rectangle on F.Silkscreen
    @(123.2410 mm, 73.7667 mm): Segment of C1 on F.Silkscreen
[silk_overlap]: Silkscreen clearance
    Rule: board setup constraints silk; warning
    @(124.6250 mm, 72.7250 mm): Rectangle on F.Silkscreen
    @(123.2410 mm, 73.8067 mm): Segment of C1 on F.Silkscreen
[silk_overlap]: Silkscreen clearance
    Rule: board setup constraints silk; warning
    @(123.2410 mm, 73.8467 mm): Segment of C1 on F.Silkscreen
    @(124.6250 mm, 72.7250 mm): Rectangle on F.Silkscreen
[silk_overlap]: Silkscreen clearance
    Rule: board setup constraints silk; warning
    @(124.6250 mm, 72.7250 mm): Rectangle on F.Silkscreen
    @(123.2410 mm, 73.8867 mm): Segment of C1 on F.Silkscreen
[silk_overlap]: Silkscreen clearance
    Rule: board setup constraints silk; warning
    @(123.2410 mm, 73.9267 mm): Segment of C1 on F.Silkscreen
    @(124.6250 mm, 72.7250 mm): Rectangle on F.Silkscreen
[silk_overlap]: Silkscreen clearance
    Rule: board setup constraints silk; warning
    @(124.6250 mm, 72.7250 mm): Rectangle on F.Silkscreen
    @(123.2410 mm, 73.9667 mm): Segment of C1 on F.Silkscreen
[silk_overlap]: Silkscreen clearance
    Rule: board setup constraints silk; warning
    @(123.2410 mm, 74.0067 mm): Segment of C1 on F.Silkscreen
    @(124.6250 mm, 72.7250 mm): Rectangle on F.Silkscreen
[silk_overlap]: Silkscreen clearance
    Rule: board setup constraints silk; warning
    @(124.6250 mm, 72.7250 mm): Rectangle on F.Silkscreen
    @(123.2410 mm, 74.0467 mm): Segment of C1 on F.Silkscreen
[silk_overlap]: Silkscreen clearance
    Rule: board setup constraints silk; warning
    @(124.6250 mm, 72.7250 mm): Rectangle on F.Silkscreen
    @(123.2410 mm, 74.0867 mm): Segment of C1 on F.Silkscreen
[silk_overlap]: Silkscreen clearance
    Rule: board setup constraints silk; warning
    @(123.2410 mm, 74.1267 mm): Segment of C1 on F.Silkscreen
    @(124.6250 mm, 72.7250 mm): Rectangle on F.Silkscreen
[silk_overlap]: Silkscreen clearance
    Rule: board setup constraints silk; warning
    @(123.2410 mm, 74.1667 mm): Segment of C1 on F.Silkscreen
    @(124.6250 mm, 72.7250 mm): Rectangle on F.Silkscreen
[silk_overlap]: Silkscreen clearance
    Rule: board setup constraints silk; warning
    @(124.6250 mm, 72.7250 mm): Rectangle on F.Silkscreen
    @(123.2410 mm, 74.2067 mm): Segment of C1 on F.Silkscreen
[silk_overlap]: Silkscreen clearance
    Rule: board setup constraints silk; warning
    @(124.6250 mm, 72.7250 mm): Rectangle on F.Silkscreen
    @(123.2410 mm, 74.2467 mm): Segment of C1 on F.Silkscreen
[silk_overlap]: Silkscreen clearance
    Rule: board setup constraints silk; warning
    @(126.4250 mm, 73.7250 mm): Rectangle on F.Silkscreen
    @(116.9200 mm, 75.6877 mm): Segment of C1 on F.Silkscreen
[silk_overlap]: Silkscreen clearance
    Rule: board setup constraints silk; warning
    @(126.4250 mm, 73.7250 mm): Rectangle on F.Silkscreen
    @(116.9200 mm, 75.7277 mm): Segment of C1 on F.Silkscreen
[silk_overlap]: Silkscreen clearance
    Rule: board setup constraints silk; warning
    @(126.4250 mm, 73.7250 mm): Rectangle on F.Silkscreen
    @(116.9200 mm, 75.7677 mm): Segment of C1 on F.Silkscreen
[silk_overlap]: Silkscreen clearance
    Rule: board setup constraints silk; warning
    @(126.4250 mm, 73.7250 mm): Rectangle on F.Silkscreen
    @(122.0000 mm, 75.7677 mm): Circle of C1 on F.Silkscreen
[silk_overlap]: Silkscreen clearance
    Rule: board setup constraints silk; warning
    @(126.4250 mm, 73.7250 mm): Rectangle on F.Silkscreen
    @(116.9210 mm, 75.6477 mm): Segment of C1 on F.Silkscreen
[silk_overlap]: Silkscreen clearance
    Rule: board setup constraints silk; warning
    @(126.4250 mm, 73.7250 mm): Rectangle on F.Silkscreen
    @(116.9220 mm, 75.6077 mm): Segment of C1 on F.Silkscreen
[silk_overlap]: Silkscreen clearance
    Rule: board setup constraints silk; warning
    @(116.9230 mm, 75.5677 mm): Segment of C1 on F.Silkscreen
    @(126.4250 mm, 73.7250 mm): Rectangle on F.Silkscreen
[silk_overlap]: Silkscreen clearance
    Rule: board setup constraints silk; warning
    @(126.4250 mm, 73.7250 mm): Rectangle on F.Silkscreen
    @(116.9250 mm, 75.5277 mm): Segment of C1 on F.Silkscreen
[silk_overlap]: Silkscreen clearance
    Rule: board setup constraints silk; warning
    @(126.4250 mm, 73.7250 mm): Rectangle on F.Silkscreen
    @(116.9270 mm, 75.4877 mm): Segment of C1 on F.Silkscreen
[silk_overlap]: Silkscreen clearance
    Rule: board setup constraints silk; warning
    @(126.4250 mm, 73.7250 mm): Rectangle on F.Silkscreen
    @(117.0720 mm, 74.5267 mm): Segment of C1 on F.Silkscreen
[silk_overlap]: Silkscreen clearance
    Rule: board setup constraints silk; warning
    @(126.4250 mm, 73.7250 mm): Rectangle on F.Silkscreen
    @(123.2410 mm, 74.2867 mm): Segment of C1 on F.Silkscreen
[silk_overlap]: Silkscreen clearance
    Rule: board setup constraints silk; warning
    @(126.4250 mm, 73.7250 mm): Rectangle on F.Silkscreen
    @(123.2410 mm, 74.3267 mm): Segment of C1 on F.Silkscreen
[silk_overlap]: Silkscreen clearance
    Rule: board setup constraints silk; warning
    @(126.4250 mm, 73.7250 mm): Rectangle on F.Silkscreen
    @(123.2410 mm, 74.3667 mm): Segment of C1 on F.Silkscreen
[silk_overlap]: Silkscreen clearance
    Rule: board setup constraints silk; warning
    @(126.4250 mm, 73.7250 mm): Rectangle on F.Silkscreen
    @(123.2410 mm, 74.4067 mm): Segment of C1 on F.Silkscreen
[silk_overlap]: Silkscreen clearance
    Rule: board setup constraints silk; warning
    @(123.2410 mm, 74.4467 mm): Segment of C1 on F.Silkscreen
    @(126.4250 mm, 73.7250 mm): Rectangle on F.Silkscreen
[silk_overlap]: Silkscreen clearance
    Rule: board setup constraints silk; warning
    @(123.2410 mm, 74.4867 mm): Segment of C1 on F.Silkscreen
    @(126.4250 mm, 73.7250 mm): Rectangle on F.Silkscreen
[silk_overlap]: Silkscreen clearance
    Rule: board setup constraints silk; warning
    @(126.4250 mm, 73.7250 mm): Rectangle on F.Silkscreen
    @(123.2410 mm, 73.6067 mm): Segment of C1 on F.Silkscreen
[silk_overlap]: Silkscreen clearance
    Rule: board setup constraints silk; warning
    @(126.4250 mm, 73.7250 mm): Rectangle on F.Silkscreen
    @(123.2410 mm, 73.6467 mm): Segment of C1 on F.Silkscreen
[silk_overlap]: Silkscreen clearance
    Rule: board setup constraints silk; warning
    @(126.4250 mm, 73.7250 mm): Rectangle on F.Silkscreen
    @(123.2410 mm, 73.6867 mm): Segment of C1 on F.Silkscreen
[silk_overlap]: Silkscreen clearance
    Rule: board setup constraints silk; warning
    @(126.4250 mm, 73.7250 mm): Rectangle on F.Silkscreen
    @(123.2410 mm, 73.7267 mm): Segment of C1 on F.Silkscreen
[silk_overlap]: Silkscreen clearance
    Rule: board setup constraints silk; warning
    @(126.4250 mm, 73.7250 mm): Rectangle on F.Silkscreen
    @(123.2410 mm, 73.7667 mm): Segment of C1 on F.Silkscreen
[silk_overlap]: Silkscreen clearance
    Rule: board setup constraints silk; warning
    @(126.4250 mm, 73.7250 mm): Rectangle on F.Silkscreen
    @(123.2410 mm, 73.8067 mm): Segment of C1 on F.Silkscreen
[silk_overlap]: Silkscreen clearance
    Rule: board setup constraints silk; warning
    @(126.4250 mm, 73.7250 mm): Rectangle on F.Silkscreen
    @(123.2410 mm, 73.8467 mm): Segment of C1 on F.Silkscreen
[silk_overlap]: Silkscreen clearance
    Rule: board setup constraints silk; warning
    @(126.4250 mm, 73.7250 mm): Rectangle on F.Silkscreen
    @(123.2410 mm, 73.8867 mm): Segment of C1 on F.Silkscreen
[silk_overlap]: Silkscreen clearance
    Rule: board setup constraints silk; warning
    @(126.4250 mm, 73.7250 mm): Rectangle on F.Silkscreen
    @(123.2410 mm, 73.9267 mm): Segment of C1 on F.Silkscreen
[silk_overlap]: Silkscreen clearance
    Rule: board setup constraints silk; warning
    @(126.4250 mm, 73.7250 mm): Rectangle on F.Silkscreen
    @(123.2410 mm, 73.9667 mm): Segment of C1 on F.Silkscreen
[silk_overlap]: Silkscreen clearance
    Rule: board setup constraints silk; warning
    @(126.4250 mm, 73.7250 mm): Rectangle on F.Silkscreen
    @(123.2410 mm, 74.0067 mm): Segment of C1 on F.Silkscreen
[silk_overlap]: Silkscreen clearance
    Rule: board setup constraints silk; warning
    @(126.4250 mm, 73.7250 mm): Rectangle on F.Silkscreen
    @(123.2410 mm, 74.0467 mm): Segment of C1 on F.Silkscreen
[silk_overlap]: Silkscreen clearance
    Rule: board setup constraints silk; warning
    @(126.4250 mm, 73.7250 mm): Rectangle on F.Silkscreen
    @(123.2410 mm, 74.0867 mm): Segment of C1 on F.Silkscreen
[silk_overlap]: Silkscreen clearance
    Rule: board setup constraints silk; warning
    @(123.2410 mm, 74.1267 mm): Segment of C1 on F.Silkscreen
    @(126.4250 mm, 73.7250 mm): Rectangle on F.Silkscreen
[silk_overlap]: Silkscreen clearance
    Rule: board setup constraints silk; warning
    @(126.4250 mm, 73.7250 mm): Rectangle on F.Silkscreen
    @(123.2410 mm, 74.1667 mm): Segment of C1 on F.Silkscreen
[silk_overlap]: Silkscreen clearance
    Rule: board setup constraints silk; warning
    @(126.4250 mm, 73.7250 mm): Rectangle on F.Silkscreen
    @(123.2410 mm, 74.2067 mm): Segment of C1 on F.Silkscreen
[silk_overlap]: Silkscreen clearance
    Rule: board setup constraints silk; warning
    @(126.4250 mm, 73.7250 mm): Rectangle on F.Silkscreen
    @(123.2410 mm, 74.2467 mm): Segment of C1 on F.Silkscreen
[silk_overlap]: Silkscreen clearance
    Rule: board setup constraints silk; warning
    @(119.6250 mm, 82.3750 mm): Segment on F.Silkscreen
    @(122.0000 mm, 81.9000 mm): Reference field of C1
[silk_overlap]: Silkscreen clearance
    Rule: board setup constraints silk; warning
    @(121.1250 mm, 80.8750 mm): Segment on F.Silkscreen
    @(122.0000 mm, 75.7677 mm): Circle of C1 on F.Silkscreen
[silk_overlap]: Silkscreen clearance
    Rule: board setup constraints silk; warning
    @(117.4600 mm, 117.6000 mm): Segment of U3 on F.Silkscreen
    @(117.8000 mm, 114.1000 mm): Reference field of R1
[silk_overlap]: Silkscreen clearance
    Rule: board setup constraints silk; warning
    @(110.3000 mm, 114.1000 mm): Reference field of R6
    @(110.8710 mm, 114.9000 mm): Reference field of C4
[silk_overlap]: Silkscreen clearance
    Rule: board setup constraints silk; warning
    @(108.3317 mm, 118.0775 mm): Segment of FB2 on F.Silkscreen
    @(108.0770 mm, 117.6300 mm): Reference field of FB1
[silk_overlap]: Silkscreen clearance
    Rule: board setup constraints silk; warning
    @(111.6060 mm, 117.1387 mm): Segment of C4 on F.Silkscreen
    @(111.4000 mm, 117.6000 mm): Reference field of U3
[silk_over_copper]: Silkscreen clipped by solder mask
    Local override; warning
    @(143.7912 mm, 103.0300 mm): Reference field of FB3
    @(142.8787 mm, 102.0600 mm): Pad 1 [Net-(U6-T-)] of FB4 on F.Cu
[silk_over_copper]: Silkscreen clipped by solder mask
    Local override; warning
    @(143.7912 mm, 103.0300 mm): Reference field of FB3
    @(144.7038 mm, 102.0600 mm): Pad 2 [Net-(J8-Pin_2)] of FB4 on F.Cu
[silk_over_copper]: Silkscreen clipped by solder mask
    Local override; warning
    @(145.1113 mm, 103.2000 mm): Reference field of J8
    @(144.7038 mm, 102.0600 mm): Pad 2 [Net-(J8-Pin_2)] of FB4 on F.Cu
[silk_over_copper]: Silkscreen clipped by solder mask
    Local override; warning
    @(142.6250 mm, 71.1750 mm): PCB text 'ST7789V3 ALIGN 32.4x17.3' on F.Silkscreen
    @(143.9000 mm, 71.9875 mm): Pad 1 [/f] of R16 on F.Cu
[silk_over_copper]: Silkscreen clipped by solder mask
    Local override; warning
    @(142.6250 mm, 71.1750 mm): PCB text 'ST7789V3 ALIGN 32.4x17.3' on F.Silkscreen
    @(146.4000 mm, 71.9875 mm): Pad 1 [/a] of R17 on F.Cu
[silk_over_copper]: Silkscreen clipped by solder mask
    Local override; warning
    @(142.6250 mm, 71.1750 mm): PCB text 'ST7789V3 ALIGN 32.4x17.3' on F.Silkscreen
    @(138.9000 mm, 71.9875 mm): Pad 1 [/b] of R15 on F.Cu
[silk_over_copper]: Silkscreen clipped by solder mask
    Local override; warning
    @(124.6250 mm, 72.7250 mm): Rectangle on F.Silkscreen
    @(160.7500 mm, 89.6600 mm): PTH pad 3 [/d] of J9
[silk_over_copper]: Silkscreen clipped by solder mask
    Local override; warning
    @(124.6250 mm, 72.7250 mm): Rectangle on F.Silkscreen
    @(124.2550 mm, 91.3000 mm): Pad 25 [/IO0] of U2 on F.Cu
[silk_over_copper]: Silkscreen clipped by solder mask
    Local override; warning
    @(126.4250 mm, 73.7250 mm): Rectangle on F.Silkscreen
    @(158.2100 mm, 89.6600 mm): PTH pad 2 [/f] of J9
[silk_over_copper]: Silkscreen clipped by solder mask
    Local override; warning
    @(126.4250 mm, 73.7250 mm): Rectangle on F.Silkscreen
    @(146.4000 mm, 73.8125 mm): Pad 2 [Net-(DS1-a)] of R17 on F.Cu
[silk_over_copper]: Silkscreen clipped by solder mask
    Local override; warning
    @(126.4250 mm, 73.7250 mm): Rectangle on F.Silkscreen
    @(143.9000 mm, 73.8125 mm): Pad 2 [Net-(DS1-f)] of R16 on F.Cu
[silk_over_copper]: Silkscreen clipped by solder mask
    Local override; warning
    @(126.4250 mm, 73.7250 mm): Rectangle on F.Silkscreen
    @(138.9000 mm, 73.8125 mm): Pad 2 [Net-(DS1-b)] of R15 on F.Cu
[silk_over_copper]: Silkscreen clipped by solder mask
    Local override; warning
    @(126.4250 mm, 73.7250 mm): Rectangle on F.Silkscreen
    @(146.5000 mm, 91.2875 mm): Pad 2 [Net-(DS1-d)] of R11 on F.Cu
[silk_over_copper]: Silkscreen clipped by solder mask
    Local override; warning
    @(126.4250 mm, 73.7250 mm): Rectangle on F.Silkscreen
    @(149.0000 mm, 91.2875 mm): Pad 2 [Net-(DS1-e)] of R10 on F.Cu
[silk_over_copper]: Silkscreen clipped by solder mask
    Local override; warning
    @(126.4250 mm, 73.7250 mm): Rectangle on F.Silkscreen
    @(138.8000 mm, 91.2875 mm): Pad 2 [Net-(DS1-g)] of R14 on F.Cu
[silk_over_copper]: Silkscreen clipped by solder mask
    Local override; warning
    @(126.4250 mm, 73.7250 mm): Rectangle on F.Silkscreen
    @(141.4000 mm, 91.2875 mm): Pad 2 [Net-(DS1-c)] of R13 on F.Cu
[silk_over_copper]: Silkscreen clipped by solder mask
    Local override; warning
    @(126.4250 mm, 73.7250 mm): Rectangle on F.Silkscreen
    @(143.9000 mm, 91.2875 mm): Pad 2 [Net-(DS1-dp)] of R12 on F.Cu
[silk_over_copper]: Silkscreen clipped by solder mask
    Local override; warning
    @(124.6250 mm, 72.7250 mm): Rectangle on F.Silkscreen
    @(134.4375 mm, 72.9000 mm): Pad 2 [GND] of C3 on F.Cu
[silk_over_copper]: Silkscreen clipped by solder mask
    Local override; warning
    @(124.6250 mm, 72.7250 mm): Rectangle on F.Silkscreen
    @(132.3625 mm, 72.9000 mm): Pad 1 [+3.3V] of C3 on F.Cu
[silk_over_copper]: Silkscreen clipped by solder mask
    Local override; warning
    @(124.6250 mm, 72.7250 mm): Rectangle on F.Silkscreen
    @(130.1375 mm, 72.9000 mm): Pad 1 [Net-(D1-+)] of C2 on F.Cu
[silk_over_copper]: Silkscreen clipped by solder mask
    Local override; warning
    @(124.6250 mm, 72.7250 mm): Rectangle on F.Silkscreen
    @(128.0625 mm, 72.9000 mm): Pad 2 [GND] of C2 on F.Cu
[silk_over_copper]: Silkscreen clipped by solder mask
    Local override; warning
    @(119.6250 mm, 82.3750 mm): Segment on F.Silkscreen
    @(118.9000 mm, 82.1500 mm): Pad 4 [GND] of D1 on F.Cu
[silk_over_copper]: Silkscreen clipped by solder mask
    Local override; warning
    @(112.9000 mm, 114.1000 mm): Reference field of C6
    @(112.9950 mm, 115.1250 mm): Pad 4 [+3.3V] of U3 on F.Cu
[silk_over_copper]: Silkscreen clipped by solder mask
    Local override; warning
    @(108.0770 mm, 117.6300 mm): Reference field of FB1
    @(107.1645 mm, 118.6000 mm): Pad 2 [Net-(J4-Pin_2)] of FB2 on F.Cu
[silk_over_copper]: Silkscreen clipped by solder mask
    Local override; warning
    @(106.6300 mm, 127.6800 mm): Reference field of J7
    @(103.7000 mm, 126.4000 mm): NPTH pad of REF**
[silk_over_copper]: Silkscreen clipped by solder mask
    Local override; warning
    @(108.0770 mm, 117.6300 mm): Reference field of FB1
    @(108.9895 mm, 118.6000 mm): Pad 1 [Net-(U3-T-)] of FB2 on F.Cu
[silk_over_copper]: Silkscreen clipped by solder mask
    Local override; warning
    @(111.4000 mm, 117.6000 mm): Reference field of U3
    @(110.8710 mm, 116.3625 mm): Pad 1 [Net-(U3-T+)] of C4 on F.Cu
[silk_over_copper]: Silkscreen clipped by solder mask
    Local override; warning
    @(111.4000 mm, 117.6000 mm): Reference field of U3
    @(110.8710 mm, 118.4375 mm): Pad 2 [Net-(U3-T-)] of C4 on F.Cu
[silk_over_copper]: Silkscreen clipped by solder mask
    Local override; warning
    @(127.5750 mm, 90.3751 mm): Segment of DS1 on B.Silkscreen
    @(155.6700 mm, 89.6600 mm): PTH pad 1 [/dp] of J9
[silk_over_copper]: Silkscreen clipped by solder mask
    Local override; warning
    @(127.5750 mm, 90.3751 mm): Segment of DS1 on B.Silkscreen
    @(158.2100 mm, 89.6600 mm): PTH pad 2 [/f] of J9
[silk_over_copper]: Silkscreen clipped by solder mask
    Local override; warning
    @(157.6750 mm, 74.3751 mm): Segment of DS1 on B.Silkscreen
    @(158.2100 mm, 89.6600 mm): PTH pad 2 [/f] of J9

** Found 0 unconnected pads **

** Found 0 Footprint errors **

** Ignored checks **
    - Footprint has no courtyard defined
    - Track endpoint not centered on via
    - Tuning profile track geometries
    - Footprint doesn't match symbol's footprint filters
    - PTH inside courtyard
    - NPTH inside courtyard

** End of Report **

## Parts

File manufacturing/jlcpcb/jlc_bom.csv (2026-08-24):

Comment | Designator | Footprint | LCSC Part # | Quantity | DNP
1000u | C1 | Capacitor_THT:CP_Radial_D10.0mm_P5.00mm |  | 1
10u | C2,C3,C5 | Capacitor_SMD:C_0805_2012Metric_Pad1.18x1.45mm_HandSolder |  | 3
0.01u | C4,C6,C7 | Capacitor_SMD:C_0805_2012Metric_Pad1.18x1.45mm_HandSolder |  | 3
100n | CCBB1 | Capacitor_THT:C_Rect_L13.0mm_W6.0mm_P10.00mm_FKS3_FKP3_MKS4 | C105712 | 1
MB6F | D1 | reflow946:MB-F | C2490 | 1
FJ4301BH | DS1 | reflow946:FJ4301BH | C10706 | 1
SMD0805-020-16V | F1 | Fuse:Fuse_0805_2012Metric_Pad1.15x1.40mm_HandSolder | C70057 | 1
FerriteBead | FB1,FB2,FB3,FB4 | Resistor_SMD:R_0603_1608Metric_Pad0.98x0.95mm_HandSolder |  | 4
VH-2A | J1 | Connector_JST:JST_VH_B2P-VH_1x02_P3.96mm_Vertical | C16728 | 1
VH-3A2 | J2,J3 | Connector_JST:JST_VH_B2P3-VH_1x02_P7.92mm_Vertical | C18157 | 2
XH-A2 | J4 | reflow946:CONN-TH_XH-2A | C20079 | 1
HDR-M-2.54_2x3 | J5 | Connector_PinHeader_2.54mm:PinHeader_2x03_P2.54mm_Vertical | C65114 | 1
TFT_1.47 | J6 | Connector_FFC-FPC:Hirose_FH12-8S-0.5SH_1x08-1MP_P0.50mm_Horizontal |  | 1
PROBE_BRK | J7 | Connector_PinHeader_2.54mm:PinHeader_1x06_P2.54mm_Vertical |  | 1
EXT_TC | J8 | TerminalBlock_Phoenix:TerminalBlock_Phoenix_MPT-0,5-2-2.54_1x02_P2.54mm_Horizontal | C20079 | 1
TFT_1.47 | J9 | Connector_PinHeader_2.54mm:PinHeader_1x08_P2.54mm_Vertical |  | 1
BTA16-600BRG | Q1 | Package_TO_SOT_THT:TO-220-3_Horizontal_TabUp | C9100 | 1
MMBT3906 | Q2,Q3,Q4 | Package_TO_SOT_SMD:SOT-23 | C181120 | 3
220R | R1,R10,R11,R12,R13,R14,R15,R16,R17 | Resistor_SMD:R_0603_1608Metric_Pad0.98x0.95mm_HandSolder |  | 9
1k | R18,R19,R20 | Resistor_SMD:R_0603_1608Metric_Pad0.98x0.95mm_HandSolder |  | 3
30R | R3 | Resistor_THT:R_Axial_DIN0309_L9.0mm_D3.2mm_P12.70mm_Horizontal |  | 1
330R | R4 | Resistor_THT:R_Axial_DIN0309_L9.0mm_D3.2mm_P12.70mm_Horizontal |  | 1
100R | R5 | Resistor_THT:R_Axial_DIN0414_L11.9mm_D4.5mm_P15.24mm_Horizontal |  | 1
10k | R6,R7,R8,R9 | Resistor_SMD:R_0603_1608Metric_Pad0.98x0.95mm_HandSolder |  | 4
SW_Push | SW1,SW2,SW3 | reflow946:SW-TH_D6C10F1LFS | C2689630 | 3
MOC3041M | U1 | Package_DIP:DIP-6_W7.62mm_LongPads | C8921 | 1
ESP32-WROOM-32U | U2 | RF_Module:ESP32-WROOM-32U | C3013938 | 1
MAX31855KASA | U3,U6 | Package_SO:SOIC-8_3.9x4.9mm_P1.27mm | C52028 | 2
AMS1117-3.3 | U4 | Package_TO_SOT_SMD:SOT-223-3_TabPin2 | C6186 | 1

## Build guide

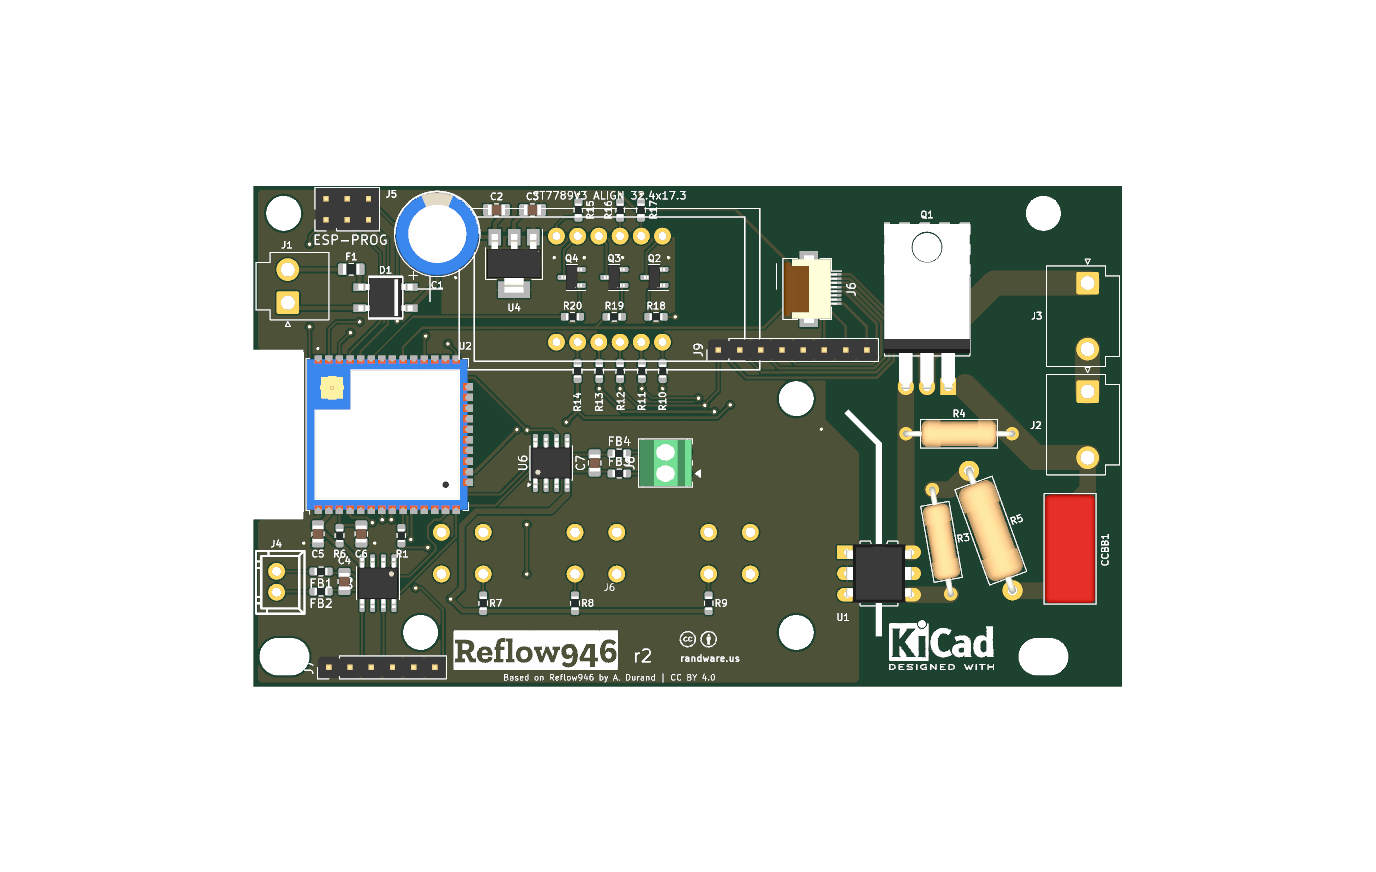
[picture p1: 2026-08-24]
manufacturing/jlcpcb/board_render_top.png

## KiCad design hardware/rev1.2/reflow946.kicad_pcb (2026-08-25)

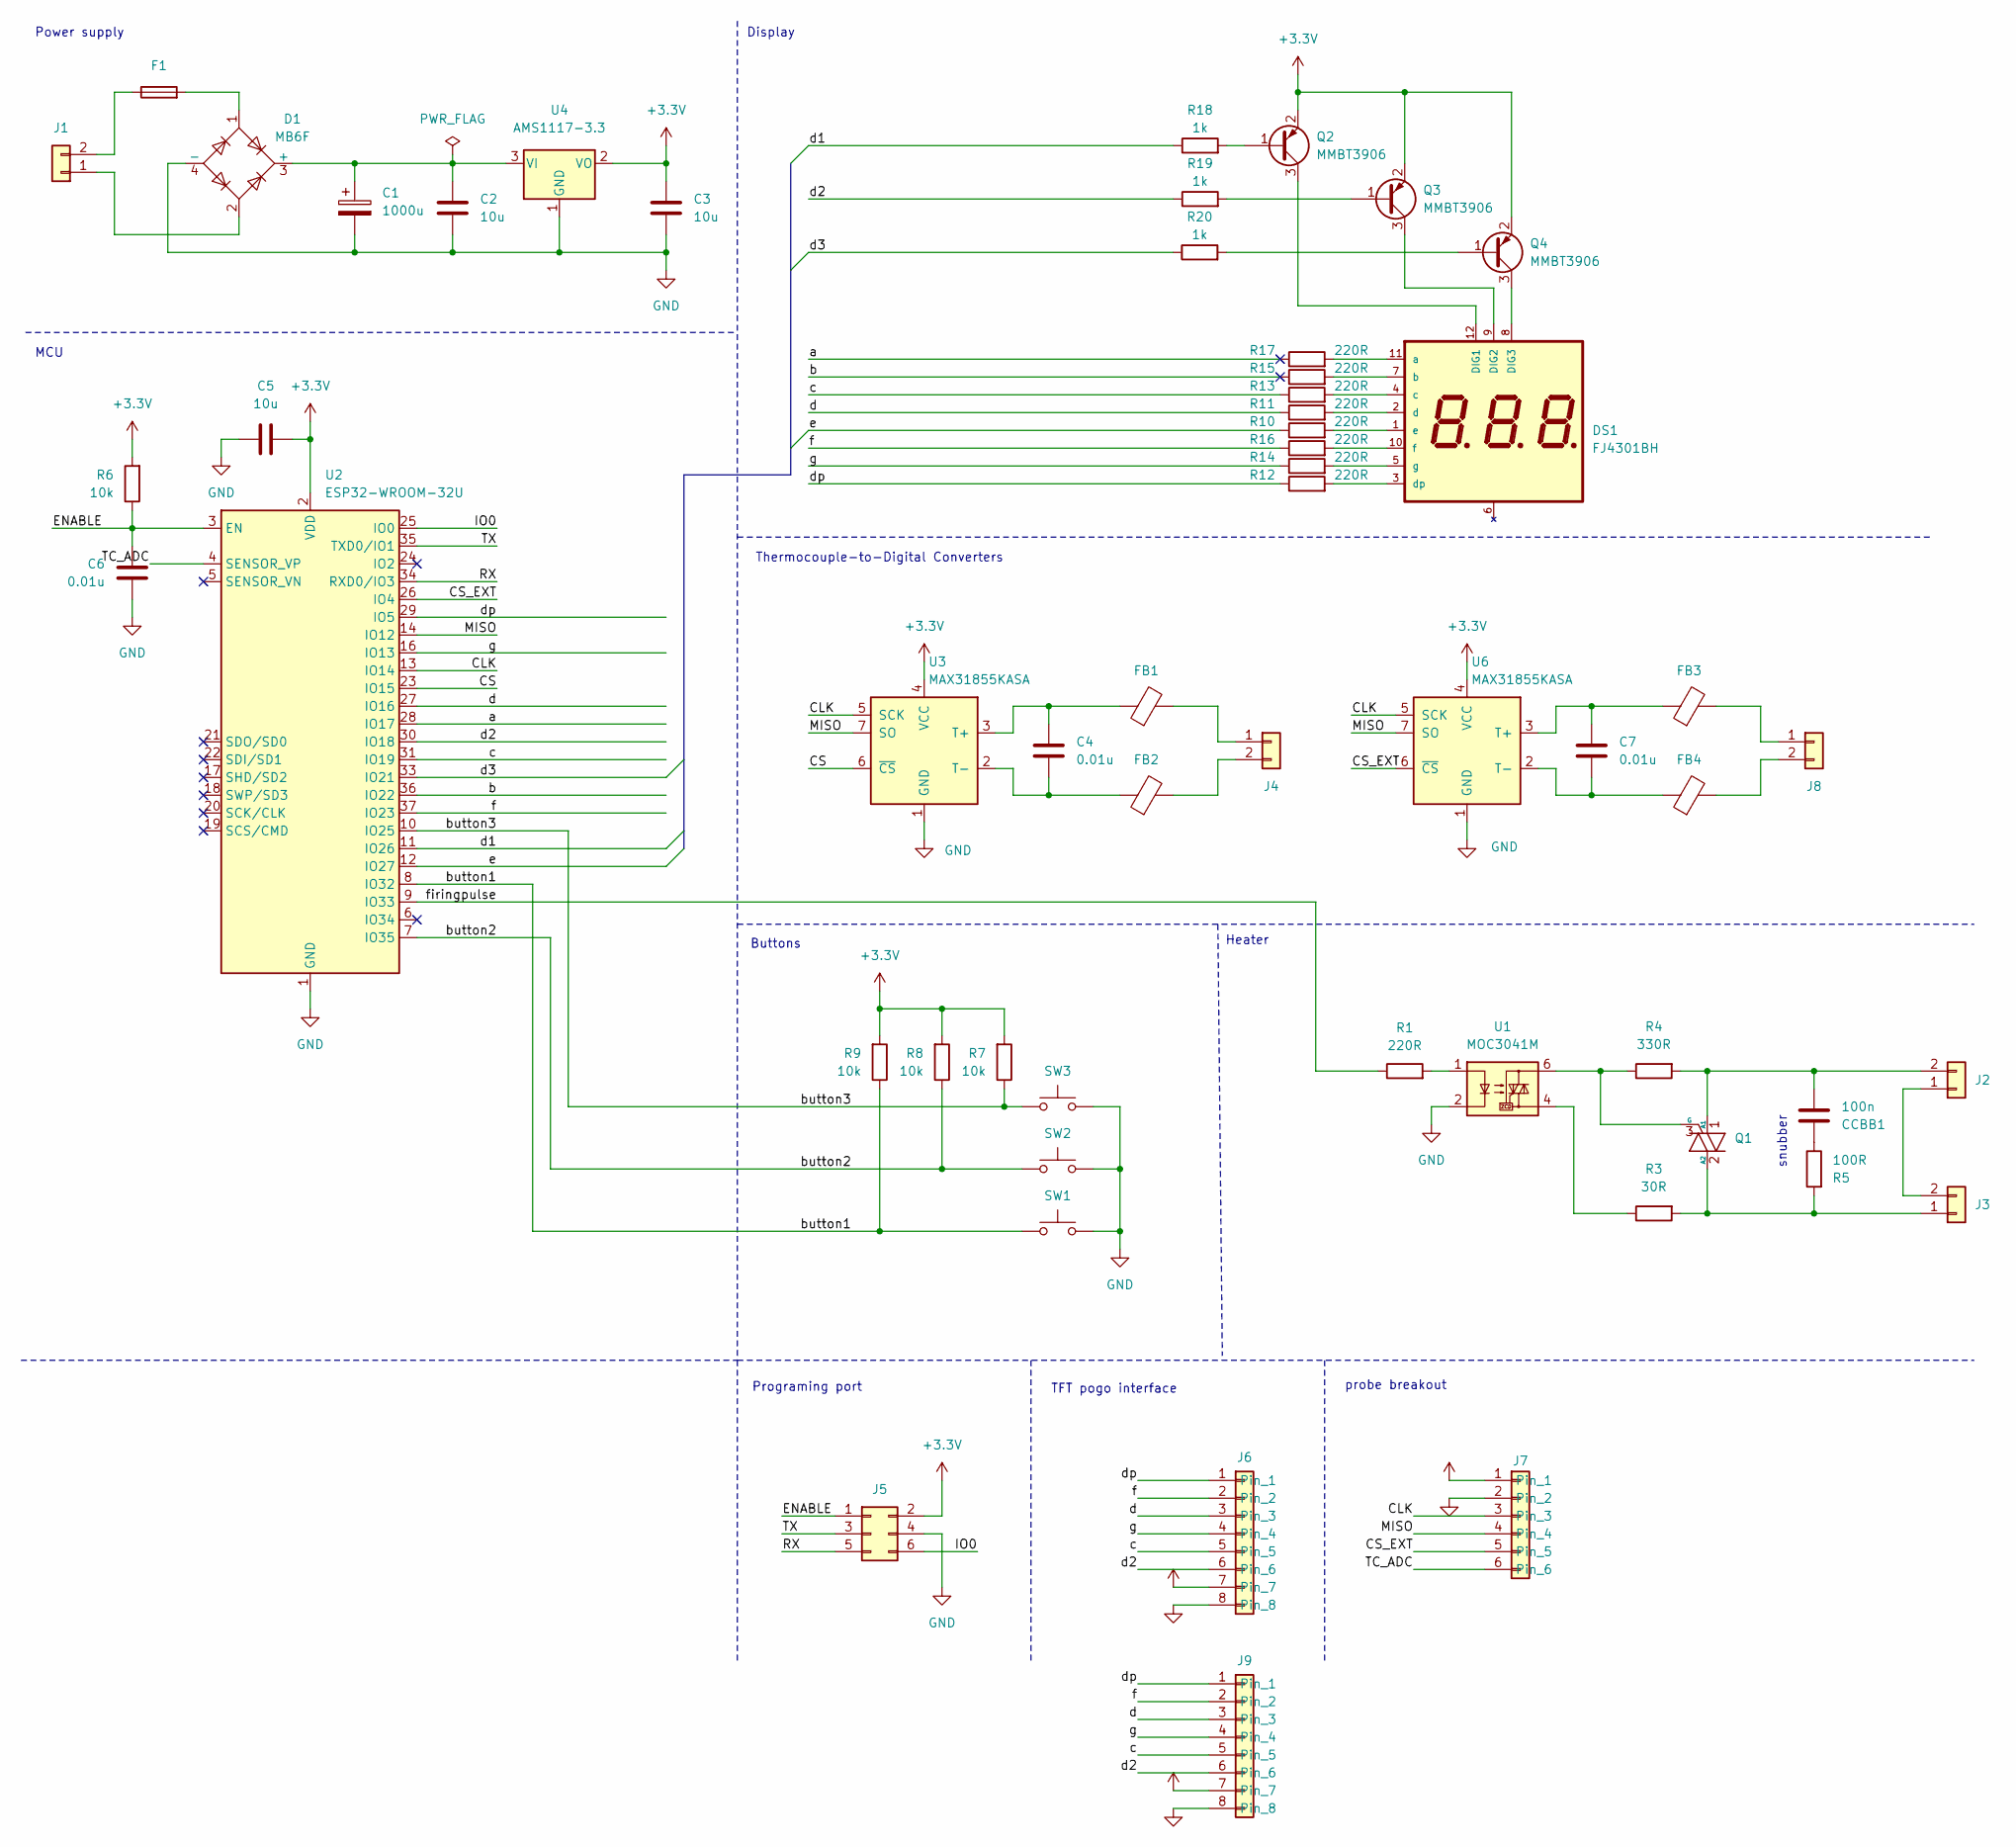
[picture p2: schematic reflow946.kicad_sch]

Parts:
C1: 1000u; CP_Radial_D10.0mm_P5.00mm
C2, C3, C5: 10u; C_0805_2012Metric_Pad1.18x1.45mm_HandSolder
C4, C6, C7: 0.01u; C_0805_2012Metric_Pad1.18x1.45mm_HandSolder
CCBB1: 100n; C_Rect_L13.0mm_W6.0mm_P10.00mm_FKS3_FKP3_MKS4; Part Number MP1104K44C3R6LC; LCSC Part # C105712
D1: MB6F; MB-F; Part Number MB6F; LCSC Part # C2490
DS1: FJ4301BH; Part Number C10706; LCSC Part # C10706
F1: SMD0805-020-16V; Fuse_0805_2012Metric_Pad1.15x1.40mm_HandSolder; Part Number SMD0805-020-16V; LCSC Part # C70057
FB1, FB2, FB3, FB4: FerriteBead; R_0603_1608Metric_Pad0.98x0.95mm_HandSolder
J1: VH-2A; JST_VH_B2P-VH_1x02_P3.96mm_Vertical; Part Number VH-2A; LCSC Part # C16728
J2, J3: VH-3A2; JST_VH_B2P3-VH_1x02_P7.92mm_Vertical; Part Number VH-3A2; LCSC Part # C18157
J4: XH-A2; CONN-TH_XH-2A; Part Number XH-2A; LCSC Part # C20079
J5: HDR-M-2.54_2x3; PinHeader_2x03_P2.54mm_Vertical; Part Number C65114; LCSC Part # C65114
J6: TFT_1.47; Hirose_FH12-8S-0.5SH_1x08-1MP_P0.50mm_Horizontal
J7: PROBE_BRK; PinHeader_1x06_P2.54mm_Vertical
J8: EXT_TC; TerminalBlock_Phoenix_MPT-0,5-2-2.54_1x02_P2.54mm_Horizontal; Part Number XH-2A; LCSC Part # C20079
J9: TFT_1.47; PinHeader_1x08_P2.54mm_Vertical
Q1: BTA16-600BRG; TO-220-3_Horizontal_TabUp; Part Number BTA16-600BRG; LCSC Part # C9100
Q2, Q3, Q4: MMBT3906; SOT-23; Part Number MMBT3906; LCSC Part # C181120
R1, R10, R11, R12, R13, R14, R15, R16, R17: 220R; R_0603_1608Metric_Pad0.98x0.95mm_HandSolder
R3: 30R; R_Axial_DIN0309_L9.0mm_D3.2mm_P12.70mm_Horizontal
R4: 330R; R_Axial_DIN0309_L9.0mm_D3.2mm_P12.70mm_Horizontal
R5: 100R; R_Axial_DIN0414_L11.9mm_D4.5mm_P15.24mm_Horizontal
R6, R7, R8, R9: 10k; R_0603_1608Metric_Pad0.98x0.95mm_HandSolder
R18, R19, R20: 1k; R_0603_1608Metric_Pad0.98x0.95mm_HandSolder
SW1, SW2, SW3: SW_Push; SW-TH_D6C10F1LFS; Part Number D6C40F1LFS; LCSC Part # C2689630
U1: MOC3041M; DIP-6_W7.62mm_LongPads; Part Number MOC3041M; LCSC Part # C8921
U2: ESP32-WROOM-32U; Part Number ESP32-WROOM-32U-H4; LCSC Part # C3013938
U3, U6: MAX31855KASA; SOIC-8_3.9x4.9mm_P1.27mm; Part Number MAX31855KASA+T; LCSC Part # C52028
U4: AMS1117-3.3; SOT-223-3_TabPin2; Part Number AMS1117-3.3; LCSC Part # C6186

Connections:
+3.3V: C3.1, C5.2, J5.2, J6.7, J7.1, J9.7, Q2.2 (E), Q3.2 (E), Q4.2 (E), R6.2, R7.2, R8.2, R9.2, U2.2 (VDD), U3.4 (VCC), U4.2 (VO), U6.4 (VCC)
/CLK: J7.3, U2.13 (IO14), U3.5 (SCK), U6.5 (SCK)
/CS: U2.23 (IO15), U3.6 (~CS)
/CS_EXT: J7.5, U2.26 (IO4), U6.6 (~CS)
/ENABLE: C6.2, J5.1, R6.1, U2.3 (EN)
/IO0: J5.6, U2.25 (IO0)
/MISO: J7.4, U2.14 (IO12), U3.7 (SO), U6.7 (SO)
/RX: J5.5, U2.34 (RXD0/IO3)
/TC_ADC: J7.6, U2.4 (SENSOR_VP)
/TX: J5.3, U2.35 (TXD0/IO1)
/a: R17.1, U2.28 (IO17)
/b: R15.1, U2.36 (IO22)
/button1: R9.1, SW1.1, U2.8 (IO32)
/button2: R8.1, SW2.1, U2.7 (IO35)
/button3: R7.1, SW3.1, U2.10 (IO25)
/c: J6.5, J9.5, R13.1, U2.31 (IO19)
/d: J6.3, J9.3, R11.1, U2.27 (IO16)
/d1: R18.1, U2.11 (IO26)
/d2: J6.6, J9.6, R19.1, U2.30 (IO18)
/d3: R20.1, U2.33 (IO21)
/dp: J6.1, J9.1, R12.1, U2.29 (IO5)
/e: R10.1, U2.12 (IO27)
/f: J6.2, J9.2, R16.1, U2.37 (IO23)
/firingpulse: R1.1, U2.9 (IO33)
/g: J6.4, J9.4, R14.1, U2.16 (IO13)
GND: C1.2, C2.2, C3.2, C5.1, C6.1, D1.4 (-), J5.4, J6.8, J7.2, J9.8, SW1.2, SW2.2, SW3.2, U1.2, U2.1 (GND), U2.15 (GND), U2.38 (GND), U2.39 (GND), U3.1 (GND), U4.1 (GND), U6.1 (GND)
unnamed: CCBB1.1, R5.1
unnamed: C1.1, C2.1, D1.3 (+), U4.3 (VI)
unnamed: D1.1, F1.2
unnamed: DS1.12 (DIG1), Q2.3 (C)
unnamed: DS1.9 (DIG2), Q3.3 (C)
unnamed: DS1.8 (DIG3), Q4.3 (C)
unnamed: DS1.11 (a), R17.2
unnamed: DS1.7 (b), R15.2
unnamed: DS1.4 (c), R13.2
unnamed: DS1.2 (d), R11.2
unnamed: DS1.3 (dp), R12.2
unnamed: DS1.1 (e), R10.2
unnamed: DS1.10 (f), R16.2
unnamed: DS1.5 (g), R14.2
unnamed: D1.2, J1.1
unnamed: F1.1, J1.2
unnamed: J2.1, J3.2
unnamed: CCBB1.2, J2.2, Q1.1 (A1), R4.2
unnamed: J3.1, Q1.2 (A2), R3.2, R5.2
unnamed: FB1.2, J4.1
unnamed: FB2.2, J4.2
unnamed: FB3.2, J8.1
unnamed: FB4.2, J8.2
unnamed: Q1.3 (G), R4.1, U1.6
unnamed: Q2.1 (B), R18.2
unnamed: Q3.1 (B), R19.2
unnamed: Q4.1 (B), R20.2
unnamed: R1.2, U1.1
unnamed: R3.1, U1.4
unnamed: C4.1, FB1.1, U3.3 (T+)
unnamed: C4.2, FB2.1, U3.2 (T-)
unnamed: C7.1, FB3.1, U6.3 (T+)
unnamed: C7.2, FB4.1, U6.2 (T-)

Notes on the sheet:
Power supply
Programing port
Thermocouple-to-Digital Converters
TFT pogo interface
snubber
probe breakout
MCU
Heater
Display
Buttons

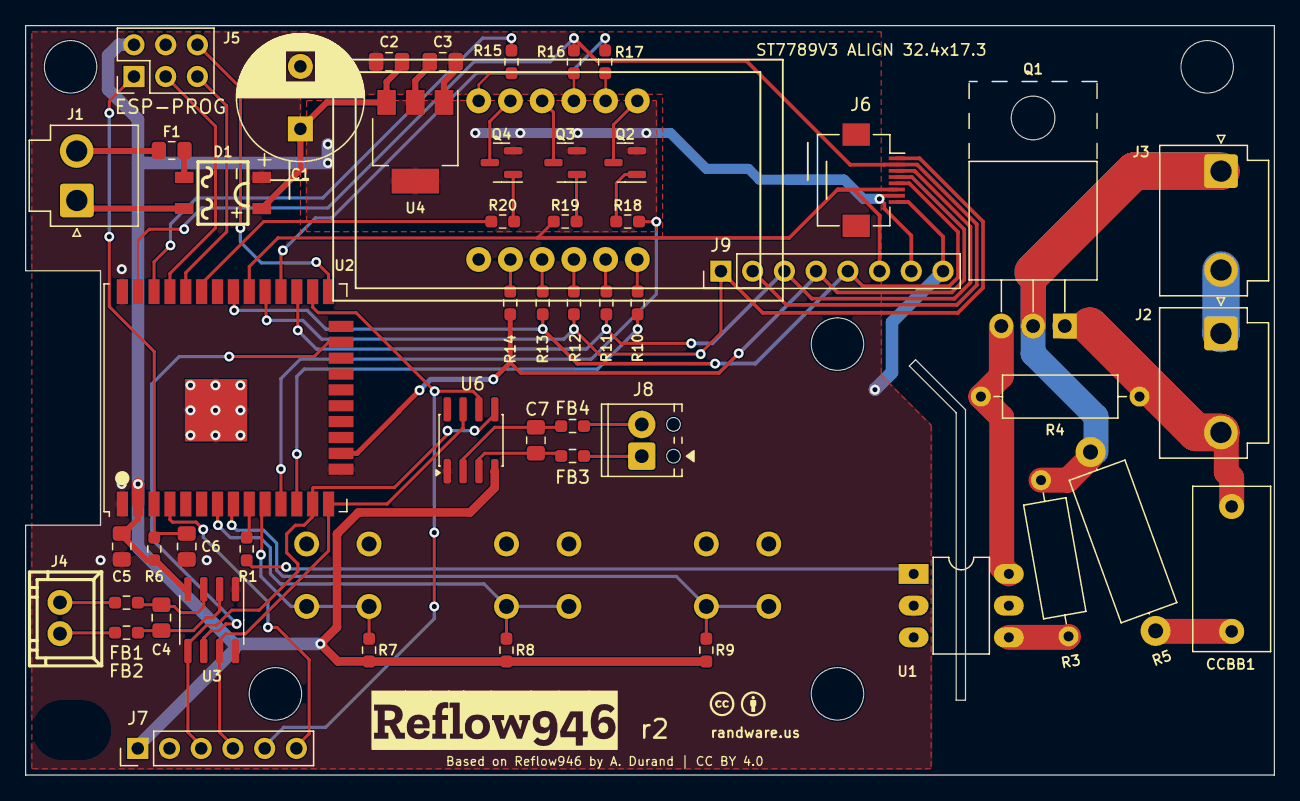
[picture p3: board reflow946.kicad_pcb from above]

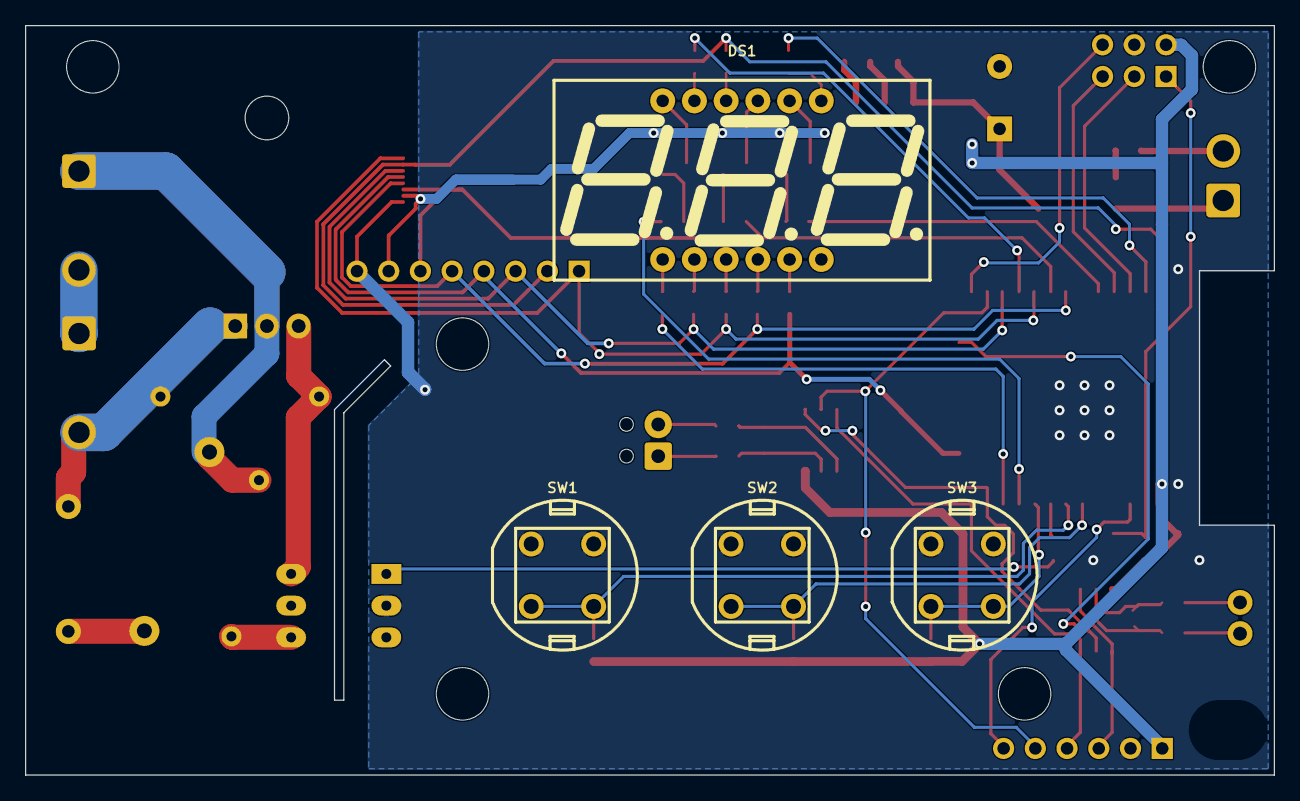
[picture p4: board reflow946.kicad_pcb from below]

Board: 2 copper layers, 100.0 x 60.0 mm, 56 parts (4 on the bottom side), 59 nets.

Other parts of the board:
kibuzzard-632CED8E: G***; kibuzzard-632CED8E

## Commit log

2026-08-22 Fork to randware R2 variant
    [reflow946.kicad_pcb, reflow946.kicad_sch]
2026-08-22 rev2 schematic: J6 display pogo interface + J7 probe breakout
    - Rename segment nets a/b -> SDA/SCL (IO17/IO22), trim dead tails
    - J6 Conn_01x04 pogo target: 3V3/GND/SDA/SCL, R21/R22 4.7k pull-ups
    - J7 Conn_01x06 breakout for external TC amp:
    CLK(IO14)/MISO(IO12) shared SPI, CS_EXT(IO4), TC_ADC(SENSOR_VP)
    - Free IO4 & SENSOR_VP no-connects; DS1 7-seg -> DNP
    - Remove orphaned a/b stubs, bus entries, dead DS1-side labels
    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
    [reflow946.kicad_sch]
2026-08-22 rev2: J6 -> 8-pin TFT SPI header, embedded U6 second MAX31855 + EXT_TC terminal
    Display path (ST7789V3 1.47in 172x320 IPS):
    - J6 Conn_01x08: 3V3/GND/CS(IO23)/DC(IO16)/RST(IO13)/SCK(IO18)/MOSI(IO19)/BLK(IO5)
    - Six freed segment GPIOs relabeled to TFT_* nets; dangling tails trimmed
    - Q3 + R19 DNP to free IO18; DS1-side dead labels/stubs/bus entries removed
    External probe subsystem:
    - U6 MAX31855KASA clone sharing CLK/MISO, CS on IO4 (CS_EXT)
    - J8 Phoenix MPT screw terminal + FB3/FB4 beads + C7 filter (mirrors U3 pattern)
    - SENSOR_VP broken out as TC_ADC; J7 breakout retained
    I2C expansion bus (IO17/IO22) kept with R21/R22 pull-ups.
    ERC: zero new functional violations vs baseline (38 vs 49 f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
    [reflow946.kicad_sch]
2026-08-22 rev2: route J6 GND stub leftward (was ending on connector body edge)
    [reflow946.kicad_sch]
2026-08-22 rev2: fix stray DNP flags on J7 power symbols; DNP Q3/R19 properly; relocate I2C pull-ups
    - #PWR0118/#PWR0120 carried stray dnp=yes (collateral of an earlier
    unbounded rindex in the Q3/R19 DNP pass) -> cleared
    - Q3 + R19 now genuinely DNP, freeing IO18 for TFT_SCK
    - R21/R22 pull-up mini-circuit moved +21.59mm clear of J6's rail stubs
    (SCL label anchor previously sat on J6's GND stub path - nets verified
    separate but one edit away from shorting)
    - ERC 38 (== baseline classes), netlist assertions all pass
    [reflow946.kicad_sch]
2026-08-22 schematic: sheet cleanup — larger canvas, arranged, bordered (manual pass)
    [reflow946.kicad_sch]
2026-08-23 pcb rev2: place all new parts, TFT alignment silk, pogo-pad J6
    - J6: custom 8x SMD pogo-pad array (dia1.6, 2.54 pitch) at bottom strip
    (inside-window THT header rejected: 11.5mm body clashes display glass;
    original location shorted existing segment copper)
    - U6/C7/FB3/FB4 probe cluster center field; J7 header top strip;
    J8 EXT_TC terminal bottom-left beside factory probe conn J4
    - R21/R22 relocated clear of Reflow946 branding and +3.3V rail track
    - Silk: ST7789V3 alignment boxes (32.4x17.3 active / 36x19.3 glass),
    fiducial crosshairs, CC BY 4.0 attribution line
    - Zones refilled; DRC vs baseline: zero new electrical/courtyard/mask
    violations; remaining = silk cosmetics + 15 unrouted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
    [reflow946.kicad_pcb]
2026-08-23 schematic: cosmetic tidy — bus reshaping, firingpulse reroute, field visibility (manual pass; netlist unchanged)
    [reflow946.kicad_sch]
2026-08-23 rev2: remove I2C expansion pull-ups R21/R22 (vestigial — display went SPI; IO17/IO22 spare)
    [reflow946.kicad_pcb, reflow946.kicad_sch]
2026-08-23 schematic: J6 pins reordered to FPC tail order (BL/CS/DC/RES/SDA/SCL/VDD/GND); footprint -> FH12-8S-0.5SH 0.5mm top-contact
    [reflow946.kicad_sch]
2026-08-23 pcb rev2: J6 -> FH12-8S-0.5SH FPC connector; segment drive chain DNP'd; orphan copper swept
    - J6 FH12 footprint below alignment window (pogo array retired:
    module is FPC-tail type, confirmed by purchased module pinout)
    - R10-R18/R20/Q2/Q4/DS1 marked DNP (7-seg path unsupported since
    segment nets became TFT_*/NC)
    - 50 orphaned no-net tracks + 16 stale TFT_* routes removed
    - zones refilled
    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
    [reflow946.kicad_pcb]
2026-08-24 rev2: restore 7-seg plug-and-play path; dual-personality architecture complete
    Schematic:
    - Segment nets fully restored (a,b,c,d,f,g,dp,d2 DS1-side labels+wires;
    U2-side SDA/SCL/TFT_* reverted to segment names; NC flags removed)
    - J6 pins now carry segment nets per FPC tail order:
    1=dp(BL) 2=f(CS) 3=d(DC) 4=g(RES) 5=c(SDA) 6=d2(SCL) 7=+3V3 8=GND
    - Segment chain un-DNP'd (DS1, R10-R20, Q2-Q4)
    Architecture: one PCB, two personalities via population —
    Board #1: DS1+segment parts fitted, FPC empty -> stock firmware, 7-seg
    Board #2: FPC+display fitted, segment parts out -> v2 firmware, TFT
    (GPIOs shared; mutually exclusive by design)
    PCB:
    - All pad nets synced to restored netlist (19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
    [reflow946.kicad_pcb, reflow946.kicad_sch]
2026-08-24 rev2: add J9 2.54mm breakout header mirroring J6 FPC signals
    - J9 PinHeader_1x08 @ bottom strip (142.6,124.3), same tail order:
    - Schematic: J9 symbol + label cluster cloned beside J6's
    - Enables bench bring-up via pogo/dupont to standard display breakouts
    while the FH12 rehearses the v2 FPC mounting path
    - Caveat: one display attached at a time (shared SPI bus)
    - DRC: zero electrical violations; 16 unrouted pads remain (J6/J9 escapes)
    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
    [reflow946.kicad_pcb, reflow946.kicad_sch]
2026-08-24 manufacturing: JLC export bundle + final DRC pass
    - Gerbers (7 layers), Excellon drill + map, JLC-format CPL (34 SMD,
    Y-flipped, THT stripped, DNP excluded), grouped JLC BOM (29 lines)
    - DRC rule severities: silk/text/mismatch classes -> warning
    - DRC final: 0 unconnected, 0 shorts/clearance/hole violations;
    remaining = silk cosmetics + baseline lib-version drift only
    - BOM gap report: LCSC part numbers needed for new parts (J6/J7/J9,
    U6, C7, FB1-FB4, R6-R20 passives)
    - README: interface description updated (FH12 + J9, shared-bus caveat)
    [jlc_bom.csv, pos_raw.csv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]
2026-08-25 Fabricate Randware v2.0 revision
    [reflow946-B_Cu.gbr, reflow946-B_Mask.gbr, reflow946-B_Paste.gbr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]
